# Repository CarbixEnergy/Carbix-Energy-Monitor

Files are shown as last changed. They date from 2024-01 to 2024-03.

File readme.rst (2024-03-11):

=========================================
Carbix Energy Monitor Project
=========================================

This is an open-source, open hardware project for monitoring energy,
forked from `IotaWatt <https://github.com/boblemaire/IoTaWatt>`_.
**We are committed to continuously optimizing supply chain costs to provide affordable hardware devices
and promote updates for this project.**

It can use any of dozens of common current transformers and will report the data locally via an integrated web server,
or upload to any of several third-party energy websites/databases.
Configuration and administration are through an easy-to-use browser-based utility running on a computer,
tablet, or smartphone.

CarbixEnergyMonitor is a full-function standalone energy monitor with the capability to store and
serve up to 15 years (or more) of comprehensive usage data and has an integrated web server with visualization apps.
At the same time, it can upload data to any of several (and counting) web-based databases and reporting systems.

Hardware is open and uses an ESP8266 nodeMCU, MCP3208 12-bit ADCs, an RTC, and an 8G SD card.

Metrics accumulated to 5-second resolution are Voltage(V), Power(Watts), Energy(kWh), VA, and PF.
While not certified to a standard, users typically report accuracy within 1% of their revenue meters.

Taking advantage of China's cost-effective supply chain, we will provide more reliable,
lower-priced energy monitors to quickly promote project development.
Now We sell Carbix energy monitor kit and current sensor accessories on `Amazon US <https://www.amazon.com/Monitor-CIRCUIT-Electricity-Open-Source-Open-Hardware/dp/B0CTCNH859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>`_,
allowing users to purchase according to their needs. For this equipment,
there is still a lot of room for cost optimization, which requires us to have a certain scale effect,
and we will work hard for this.

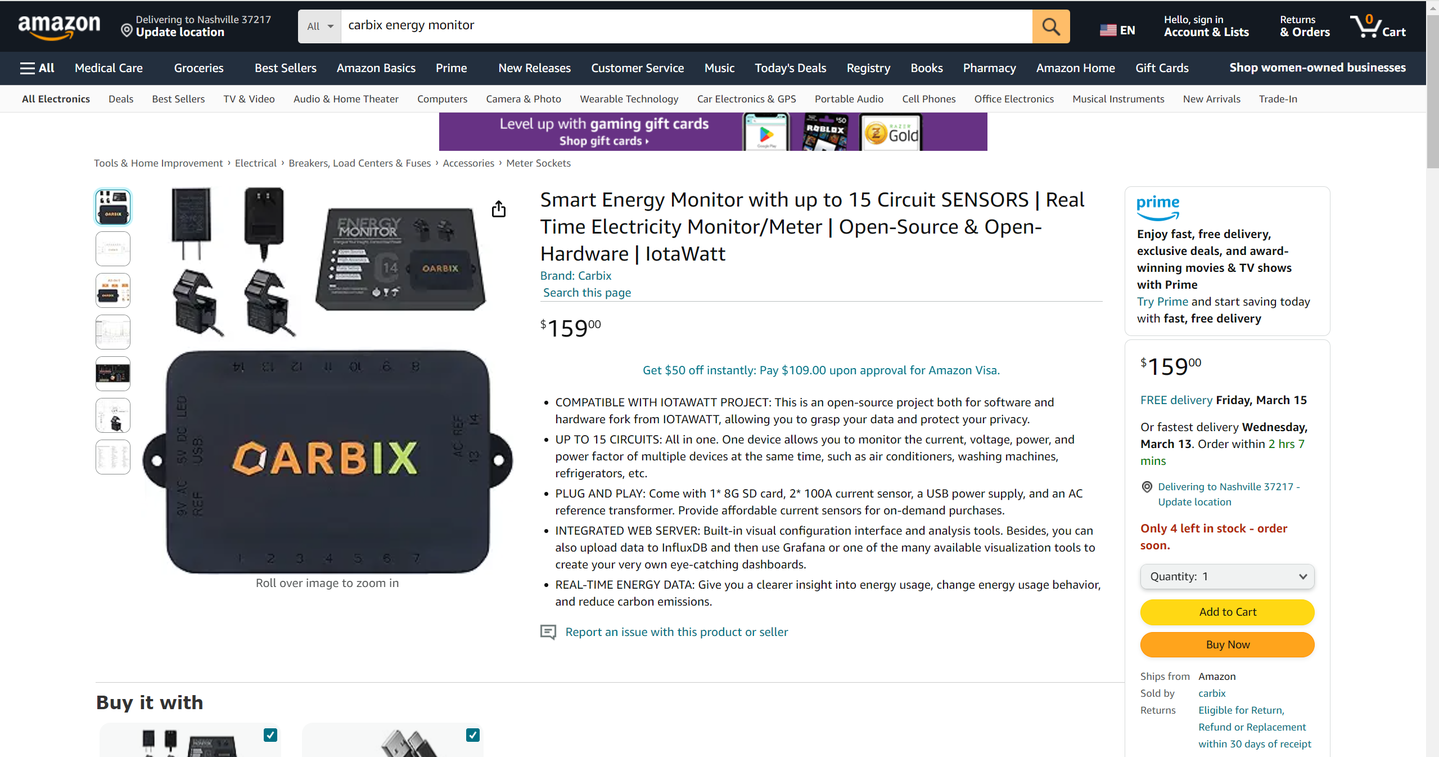
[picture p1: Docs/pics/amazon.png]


Thanks to Bob Lemaire the founder of IotaWatt for doing such a great job, we will continue to promote the open source development of this project.

`Documentation <https://carbix-energy-monitor.readthedocs.io/en/latest/>`_

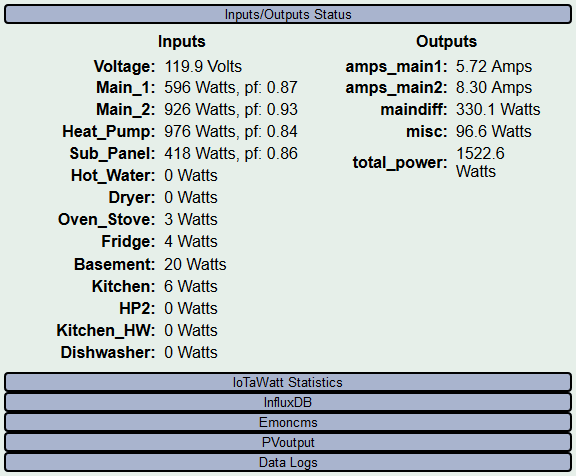
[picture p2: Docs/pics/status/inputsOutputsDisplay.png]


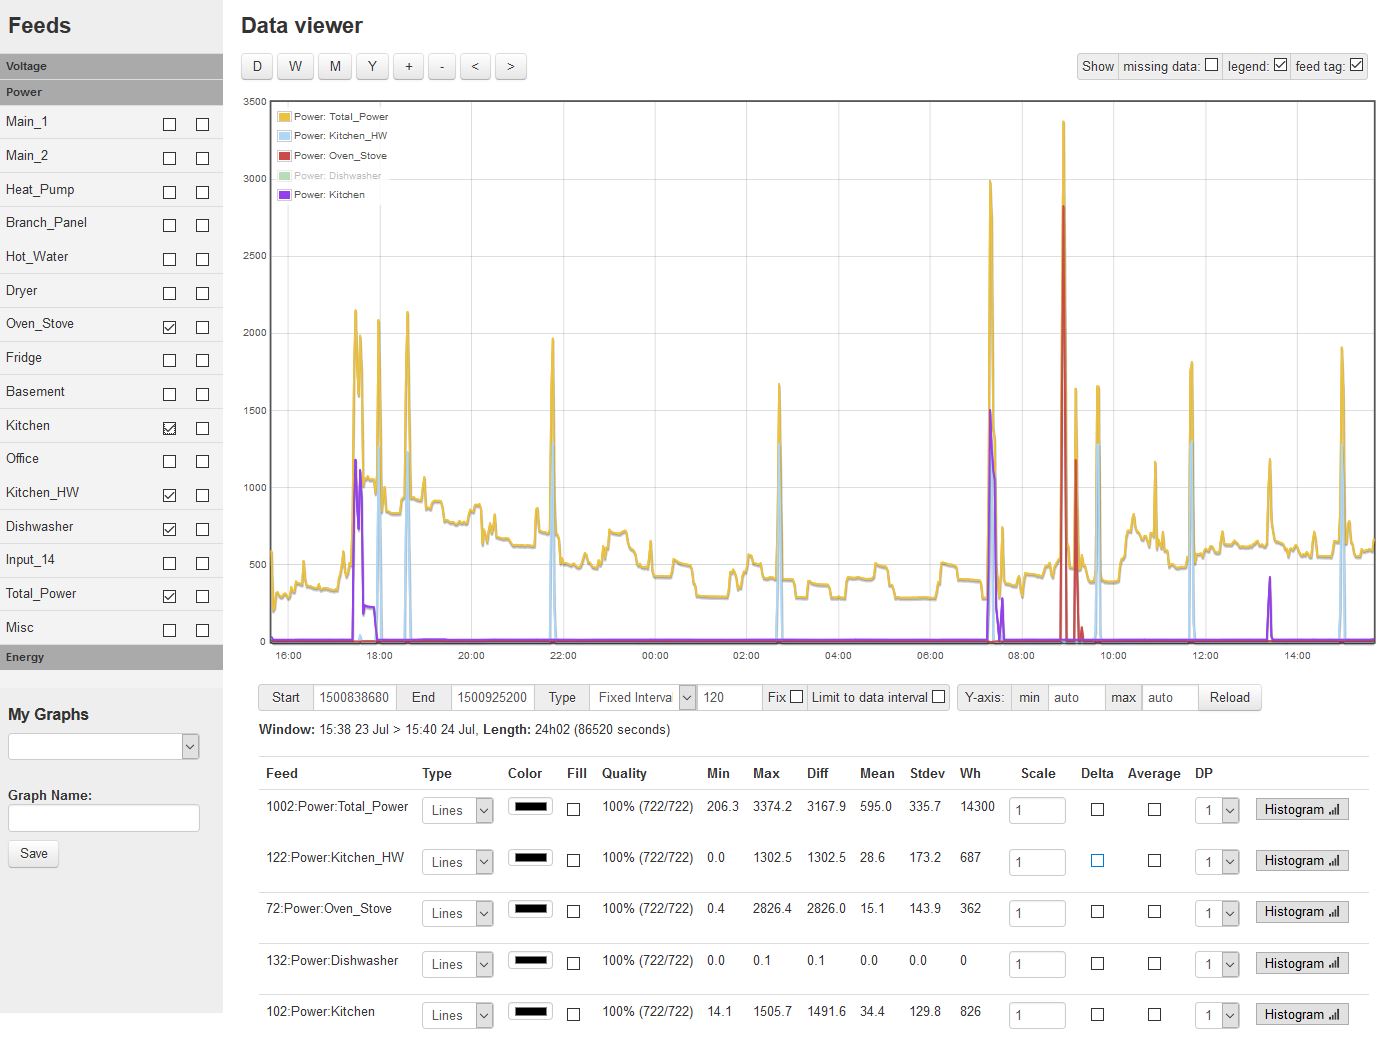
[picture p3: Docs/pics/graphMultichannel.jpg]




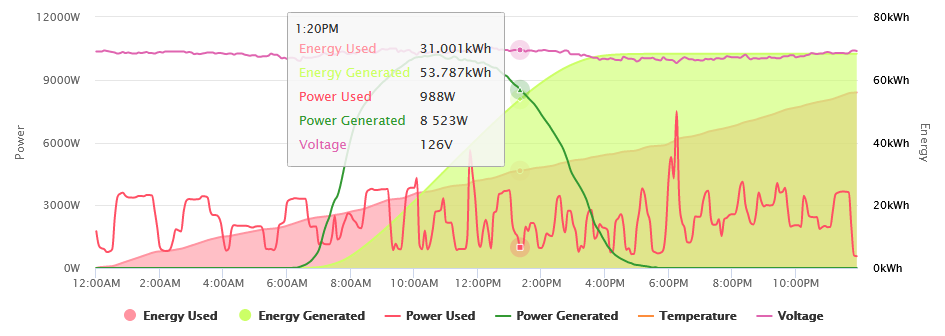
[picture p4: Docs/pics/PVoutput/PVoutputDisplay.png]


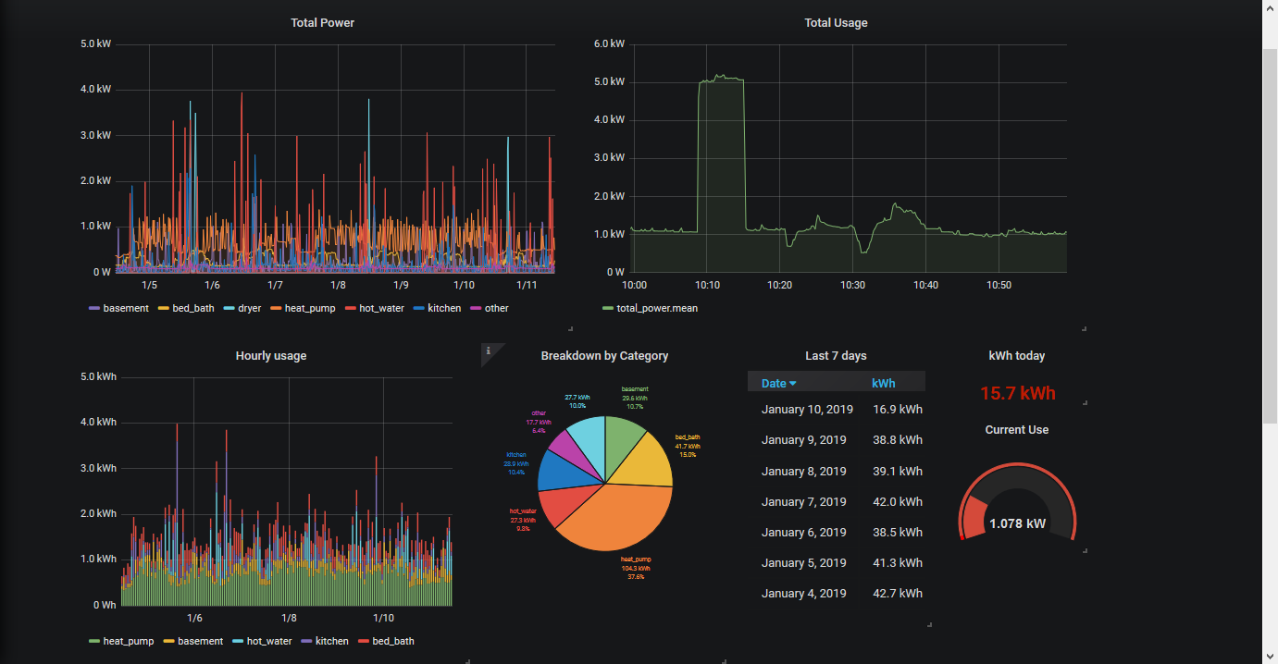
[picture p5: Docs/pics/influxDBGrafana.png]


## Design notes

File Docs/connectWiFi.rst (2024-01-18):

==================
Connecting to WiFi
==================

Purpose
-------

When CarbixEnergyMonitor powers up, it attempts to connect to the
last WiFi network used.
A connection must be established to an internet connected network if the real
time clock is not set, or to run the configuration utility,
or if logging to an external server like Emoncms is desired.
*It is strongly recommended to connect the CarbixEnergyMonitor to a WiFi network
with a reliable internet connection*.

If the power-up connection is successful, 
the LED will begin to glow dull green.
This indicates that the CarbixEnergyMonitor has connected
and is in normal operating mode.
At this point you can skip ahead to the next 
section `Device Configuration <devConfig.html>`__

New connection
--------------

If the CarbixEnergyMonitor has never been connected to a WiFi network (new),
or the last used network is not available, the ESP8266 will enter
AP (Access Point) mode when powered-up (not on a software restart).
This state is indicated when the LED flashes the 
three color sequence RED-GREEN-GREEN.
It will broadcast an SSID recognizable by the 
prefix ``carbix`` followed by a unique number.
Connect to it using a smartphone or tablet.  
Use the password ``CarbixEnergyMonitor`` (case sensitive).
If the device was previously configured and the 
device name was changed,
that new name will be the password required in this step.

After connecting, a page will be rendered with several choices.  Select ``Configure WiFi``.

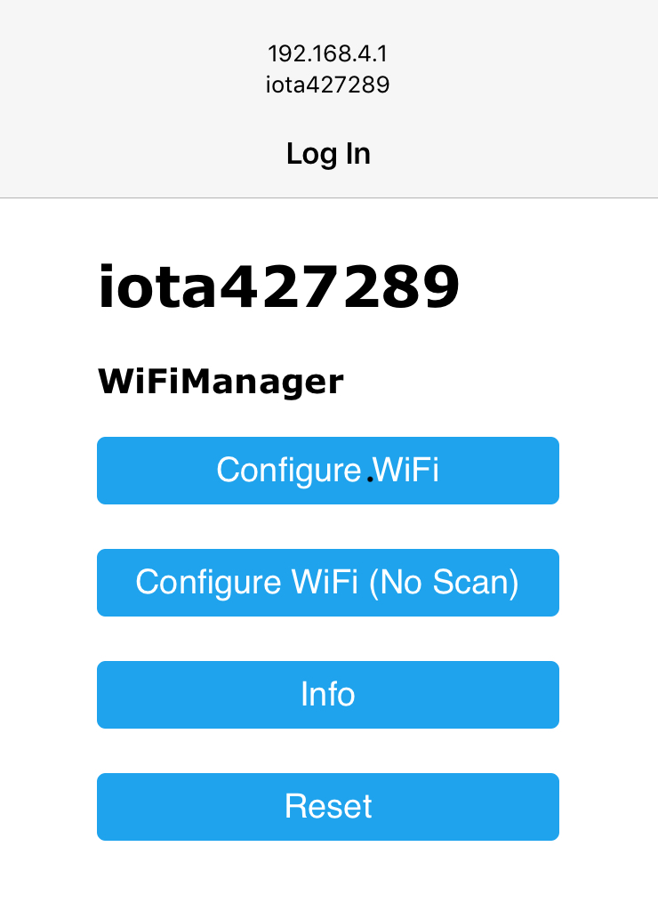
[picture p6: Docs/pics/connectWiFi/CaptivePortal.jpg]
captive portal image


A few seconds may elapse while the CarbixEnergyMonitor scans for the local networks,
then another page will be rendered allowing you to select one of the listed
networks, or specify another network not listed.

Note that the CarbixEnergyMonitor only supports 2.4 GHz wireless networks. If you have a 5 GHz
only network you can either enable 2.4 GHz on it, or create a separate (optionally hidden)
network on 2.4 GHz for the CarbixEnergyMonitor to use.

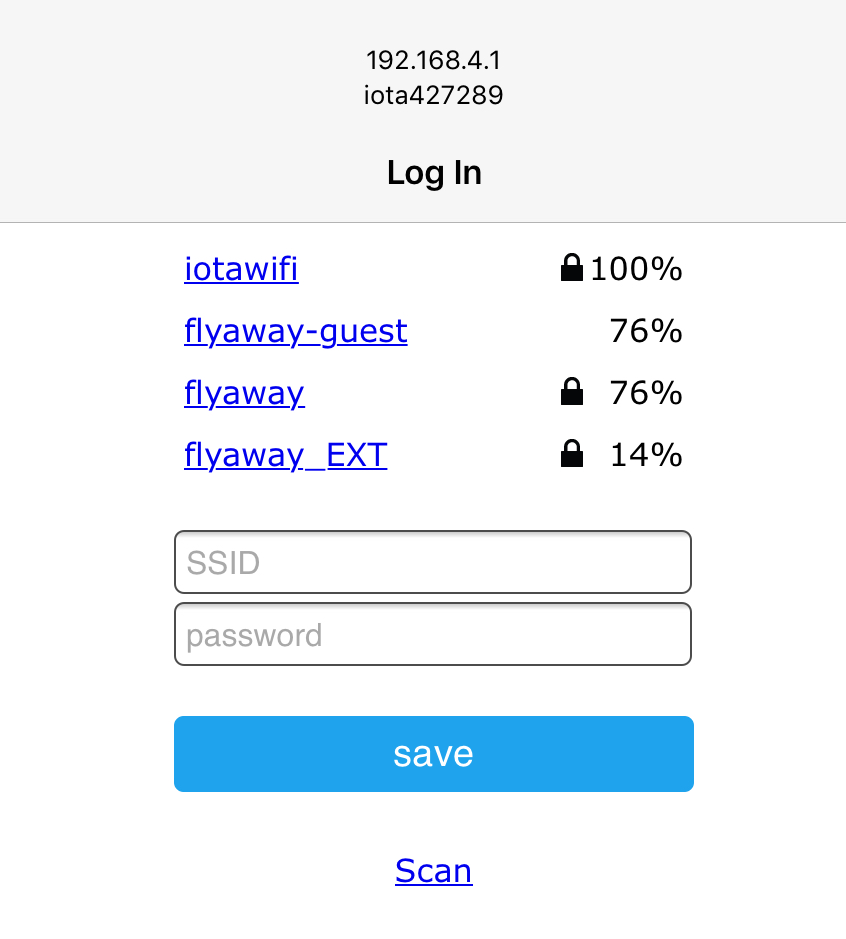
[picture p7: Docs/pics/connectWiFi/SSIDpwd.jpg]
Specify Network image


Select your network and enter the password, then save. Once connected,
the new WiFi network credentials will be saved and the device 
will continue it's
startup procedure.  If you see another LED sequence, refer to 
the `troubleshooting <troubleshooting.html>`__ section.

When the LED glows dull green, proceed to the next step
`Device Configuration  <devConfig.html>`__

Resetting WiFi to Defaults
--------------------------

If you wish to change the WiFi SSID that the CarbixEnergyMonitor is connected to
(you might have done some testing and want to deploy 'live' somewhere where the SSID is different)
BEFORE moving the device you should reset the WiFi.

Using the configuration app go to ``Tools->WiFi``

Disconnect WiFi image

After the command to disconnect the existing WiFi connection has been sent, 
CarbixEnergyMonitor will respond "ok" and the LED will change from a dull green to a dull red as the CarbixEnergyMonitor disconnects,
indicating that the WiFi link has been severed.

Then power cycle the CarbixEnergyMonitor. It should restart with the RED-GREEN-GREEN led sequence like a new
CarbixEnergyMonitor ready to connect to the new SSID

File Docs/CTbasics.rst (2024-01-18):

=========
CT Basics
=========

What is a Current Transformer?
------------------------------

`From Wikipedia <https://en.wikipedia.org/wiki/Current_transformer>`_:

    *A current transformer (CT) is a type of transformer that 
    is used to measure alternating current (AC). 
    It produces a current in its secondary which is 
    proportional to the current in its primary.* 

In our case, the primary is *one* of the conductors of the circuit
that we want to measure, and the secondary is the output jack
that plugs into the CarbixEnergyMonitor.

So without connecting anything directly to any high-voltage
wiring, it's possible to get a scaled down measure of the
primary current that can be used to passively measure power 
(Watts) of a circuit.

Types of CTs
------------

CTs come in various types, sizes, and capacities, 
and are made for a variety of end uses. This tutorial
doesn't try to address all aspects.  That's what
Wikipedia does well.  Here we'll try to focus on the
CTs that are suited to use with the CarbixEnergyMonitor in typical
scenarios.

Physically, a CT needs to have an iron core through
which one or more primary conductors pass. The most basic
type is a solid-core CT, where an iron doughnut is wrapped 
with turns of wire. This type of CT is relatively inexpensive,
typically very accurate, but requires that the primary
conductor be disconnected and reconnected to install, thus
exposing the installer to high-voltage and disrupting the
primary circuit.

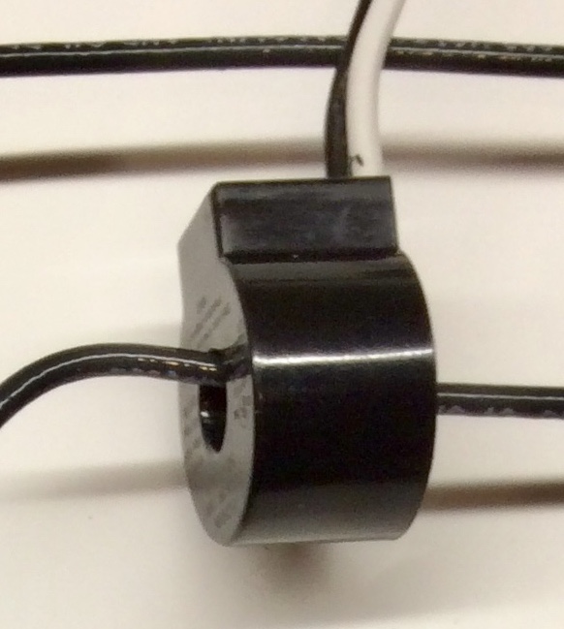
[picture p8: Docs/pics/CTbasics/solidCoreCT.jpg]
Solid Core CT


    Solid Core CT

Split-core CTs also require an iron core around the primary,
but do so using two hinged halves that mate to form the continuous
iron loop. This type of CT can be installed by simply snapping
the two halves over an active primary conductor.

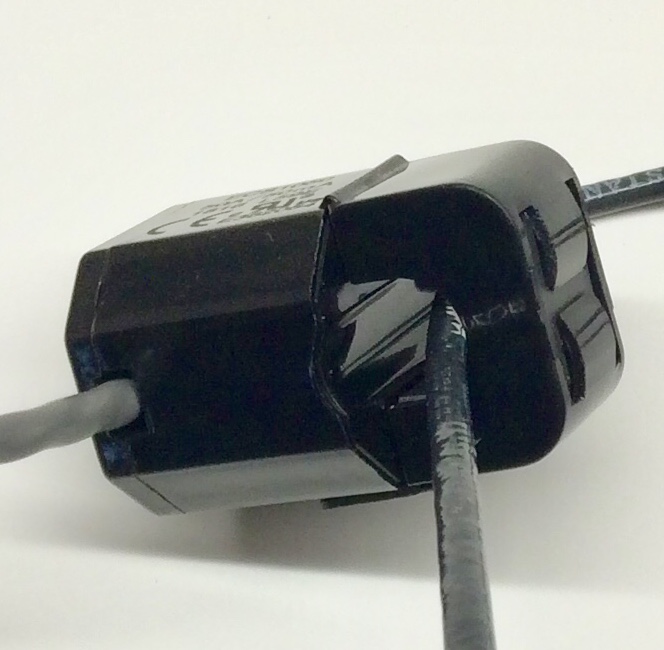
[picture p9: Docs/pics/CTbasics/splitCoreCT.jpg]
Split Core CT


    Split Core CT

Installation
------------

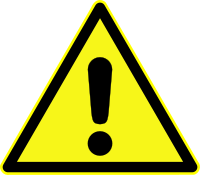
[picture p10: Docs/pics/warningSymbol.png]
**Warning!**


*The installation of CTs can be dangerous and/or
cause hazardous situations resulting serious injury or death.
Worldwide, there are a variety of electrical conventions, regulations 
and standards.  It is the user's responsibility to insure that the 
installer is qualified and all local codes and regulations are followed.*

To measure the current in a circuit, a CT is installed on one, and 
only one, of the conductors in a circuit. Either the conductor is
passed through the solid-core, or the split-core is clamped over it.

CTs must have a load.  Without a load, they will develop very 
high voltages that can damage the core windings and/or 
create a safety hazard. When plugged into the CarbixEnergyMonitor, the
secondary windings are loaded by a *burden resistor*.

Some CTs have protective diodes, called TVS diodes, that will 
protect against damage when unplugged for short periods.  Even if
a diode protected CT is to be unplugged for an extended length 
of time where the primary is energized, the CT should be removed 
or shorted.  Shorting will not damage the CT.

Polarity
--------

CTs are manufactured to produce a secondary current that is in 
phase with the primary current when installed with a particular 
orientation. In single and split-phase installations it is
important to observe polarity in certain situations.  In
three-phase installations, it is imperitive that a polarity 
convention be observed.

CarbixEnergyMonitor will accept many different CTs from different manufacturers.
While most have some type of markings that can be used as a 
reference for polarity, there is no universal standard.  Typically,
CTs from the same manufacturer will be consistent with respect to source 
and load indicators.

And so it is for the Echun and AccuEnergy CTs that CarbixEnergyMonitor, Inc makes available.
When installing, we use the notion of a *source* and a *load*.
The source can be conceptualized as *where the power comes from* 
and the load as *where the power goes*.

So for the mains, or incoming power to a service, the *source* would 
be the meter side, or incoming power feed.  The *load* would be the 
main circuit breaker or fuse side.

For branch circuits, it would be just the opposite.  The *source* would
be the circuit-breaker side, and the *load* would be the appliance side.

For a solar inverter connection, the *source* would be the inverter side, 
and the *load* would be the circuit-breaker or other point of
interconnect.

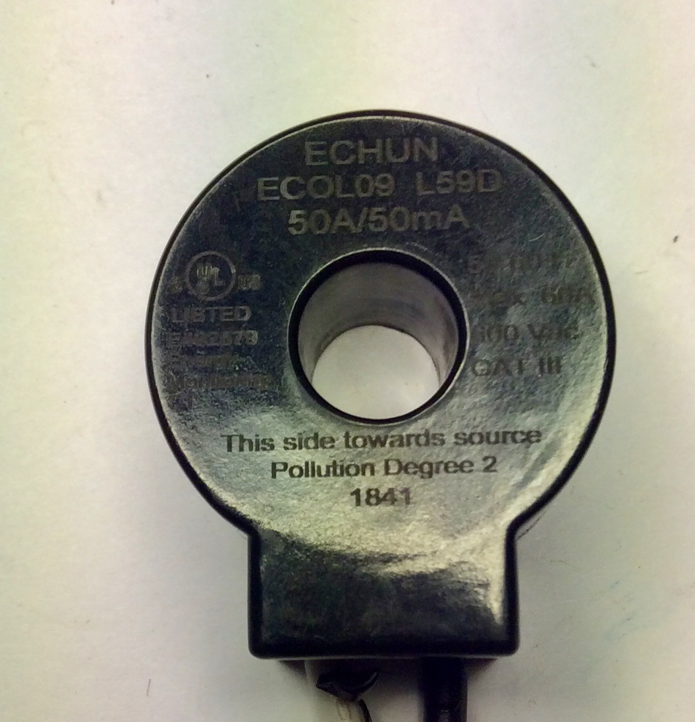
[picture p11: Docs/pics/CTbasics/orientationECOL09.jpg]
ECOL09


    Here you can plainly see "This side toward source"

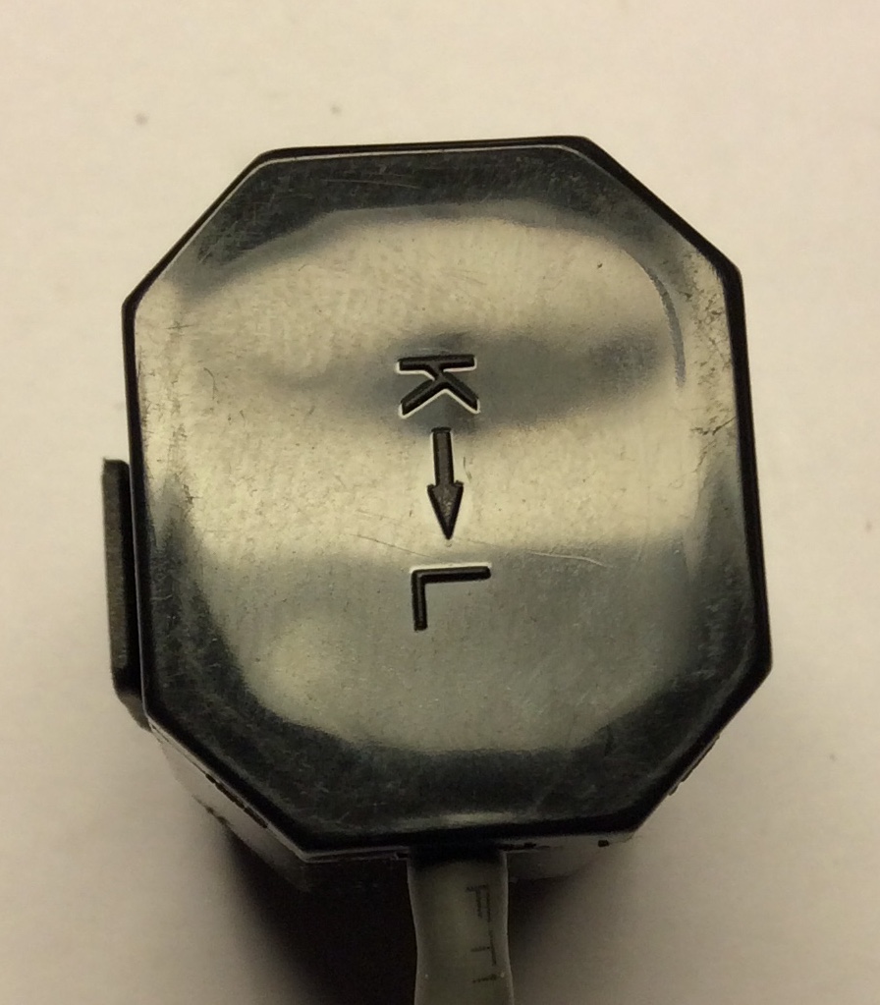
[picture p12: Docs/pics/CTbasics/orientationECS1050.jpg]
ECS1050


    Here the arrow points source(K)->load(L)

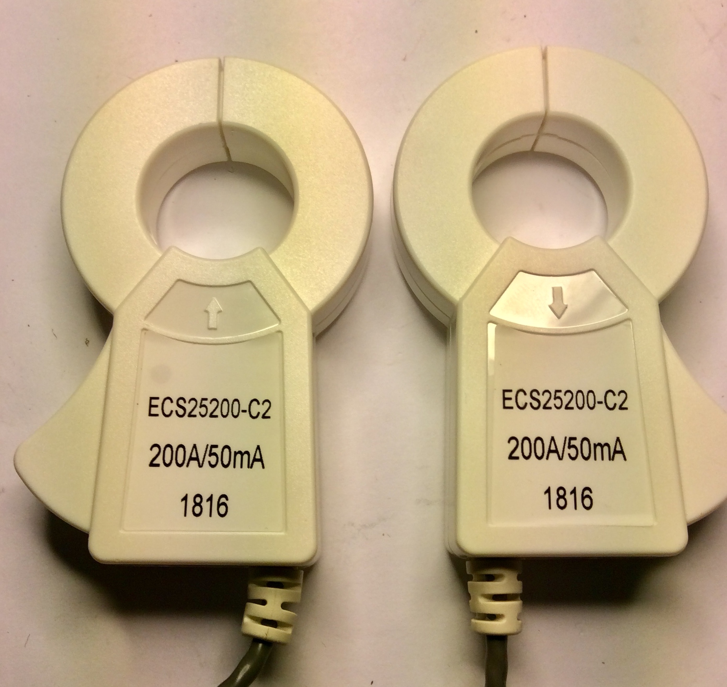
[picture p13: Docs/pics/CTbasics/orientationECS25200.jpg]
ECS25200


    This is an Echun ECS25200 clamp type CT
    used for 200A mains. Both sides are shown.
    Note the arrows just under the opening.
    The arrow pointing up to the opening
    indicates the source side, and the down
    arrow indicates the load side.

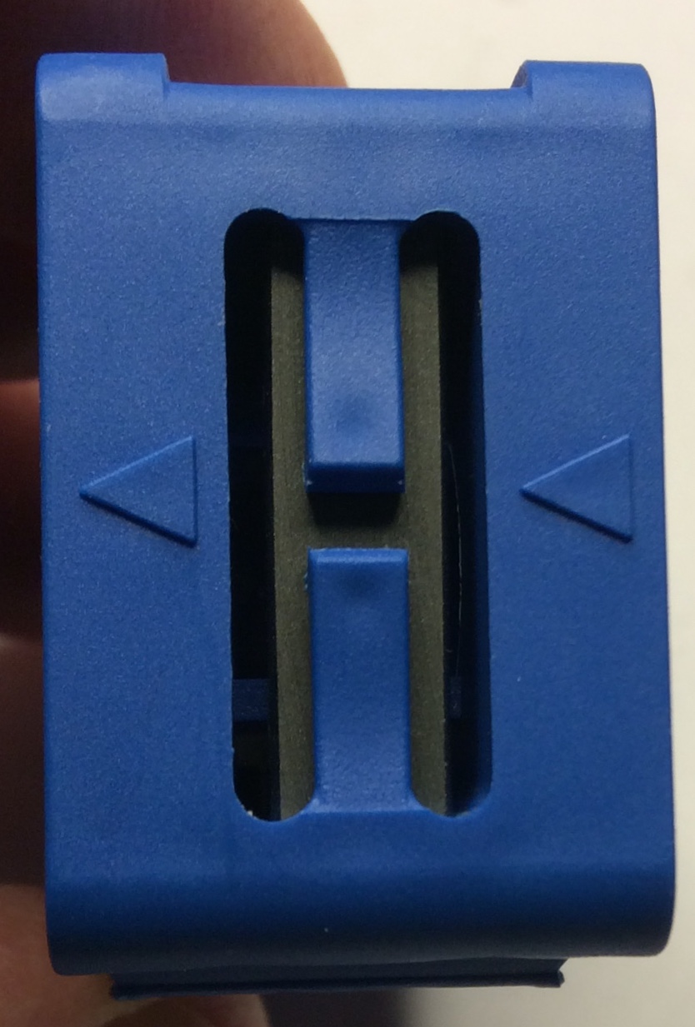
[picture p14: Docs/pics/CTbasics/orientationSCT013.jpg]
SCT013


    This is the common SCT013 CT.  If you are using
    them exclusively, the arrow can be aligned consistently
    as source to load.  But note that if using with 
    the Echun CTs, they must be installed with the
    arrow pointing from load to source.  This isn't
    a fault of either manufacturer.  It just reflects
    the lack of a standard for how to connect the
    CT secondary to the 3.5mm jack used to connect.

Single and three-phase systems
------------------------------

All of the CTs in single or three-phase systems should
be installed identically with respect to load and 
source.  This is especially important when configuring 
three-phase systems using the 
`Derived Three-phase <threePhase.html>`_ method.

Split-phase systems
-------------------

Most of North America and some Asian countries use 
a split-phase power system with dual voltage, typically 
120/240V.  With this power system, there are two mains 
with exact opposite phase. The voltage between either
main and neutral is 120V, while the voltage between 
the two mains is 240V.  This provides an advantage of 
the relative safety of lower voltage in small appliance
outlets, while still providing high voltage for 
workhorse appliances like water-heaters, ranges, 
and clothes dryers.

In these systems, while possible to use two voltage references,
typical CarbixEnergyMonitor installations use a single reference
that reflects the phase and voltage of one of the sides, 
or *legs* as they are commonly called. The result is that 
CTs on the other leg should be oriented  the opposite way to
be in phase with the opposite voltage reference. For simple singlephase 120V
(or 230V European type) circuits, CarbixEnergyMonitor will automatically correct
reversed CTs and report positive power unless "Allow negative values" is
enabled in setup for that CT.

There is more to installing CTs on 240V circuits in split-phase 
systems in the next chapter.

240V Split-phase circuits
-------------------------

As explained above, split-phase systems can provide 
high-voltage for large appliances. These circuits are connected 
to two adjascent CTs that are on different legs.  The usual
convention is to use RED and BLACK wires or, as explained below, 
BLACK and WHITE for *pure* 240V circuits.

240V only
^^^^^^^^^

When I say *pure* 240V circuits, I mean circuits that are 
usually a single load, and do not have a third neutral wire 
to use either leg independently for 120V.  Examples of *pure* 240V 
circuits would be a resistive water-heater, well-pump and 
baseboard electric heater. What these circuits will have in common
is that they don't have a neutral wire, and usually use two 
conductor with ground BLACK and WHITE leads.

With these circuits, you can place the CT on just one of the
conductors, and check the *double* box in input configuration, 
directing CarbixEnergyMonitor to double the voltage value to report
correct power and amperage.

120/240V circuits
^^^^^^^^^^^^^^^^^

Like the *pure* 240V circuits above, these circuits use two 
adjascent circuit-breakers, but also have a neutral conductor. 
They usually have RED and BLACK conductors on the circuit-breaker 
and a white neutral conductor that connects to the neutral bussbar. 
Typical appliances are ranges, ovens, and clothes-dryers.  Circuits
feeding sub-panels are usually of this type as well.

For these circuits, the two legs must be measured individually 
because the current in each is not always the same.  There are a couple 
of ways to do this.

The easiest way is to pass both the RED and BLACK conductors through 
the CT.  A CT will measure the total current of all of the conductors 
that pass through the primary.  But there is a twist.  The phase of 
the current in each conductor is exactly opposite the other, so they 
will cancel each other out. Rather than get the sum of the two,
you get the difference between the two.

The solution is to pass one conductor through in the opposite direction 
to the other.  There is a common trick for this.  In many panels,
the conductors are brought past the CT in a U shape so that there is
some excess wire in case the circuit needs to be moved within the panel. 
You can use this U configuration to easily reverse one of the conductors.
In this case, the CT needs to handle the combined capacity of the two 
circuit breakers when added together.  
A 50A CT can probably be used up to about a 2x30A breaker.

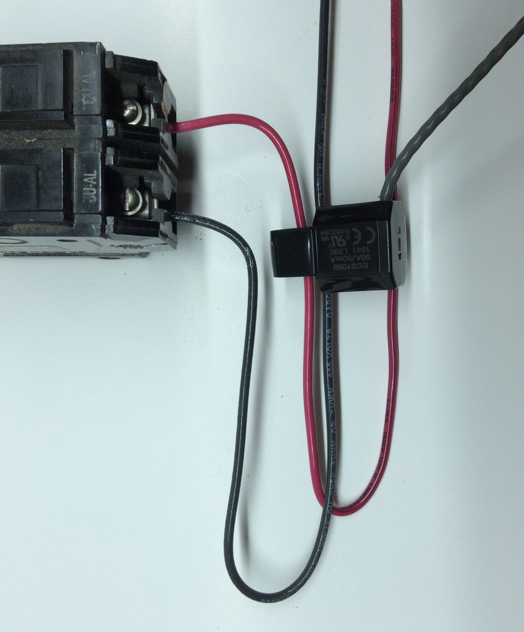
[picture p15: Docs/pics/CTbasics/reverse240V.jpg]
Reversed CT conductors


    The CT is clamped around the RED wire going down and 
    the BLACK wire going up.

An alternate method, and recommended with high amperage 
sub-panel circuits, is to put a separate CT on each leg. 
The CTs can be connected to two individual CarbixEnergyMonitor inputs
and added together later for the total.  With this method, 
each of the two CTs only need match the capacity of one of 
the circuit breakers.

Two individual CTs can also be combined with a common headphone
splitter and fed into a single CarbixEnergyMonitor input. When combining
this way, both CTs must be the same model with an individual 
capacity sufficient to measure the combined capacity of the two 
circuit breakers.

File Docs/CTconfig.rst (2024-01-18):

================================
Configuring Power Channels (CTs)
================================

What is a power channel?
------------------------

Power channels measure the current flow through a circuit and 
combine that with the reference voltage to determine power, 
expressed in watts, and to accumulate energy used, expressed in watt-hours.  
Current through a circuit is measured indirectly by installing a passive 
sensor, called a *current transformer* (CT), around one of the conductors 
in the circuit. 
CTs come in a various capacities, physical connection type, and electrical output.  

The good news is that CarbixEnergyMonitor supports a wide variety of readily available
CTs, and many can be configured simply by selecting the model from a list. 
CTs are connected with 3.5mm stereo jacks (headphone jacks). 

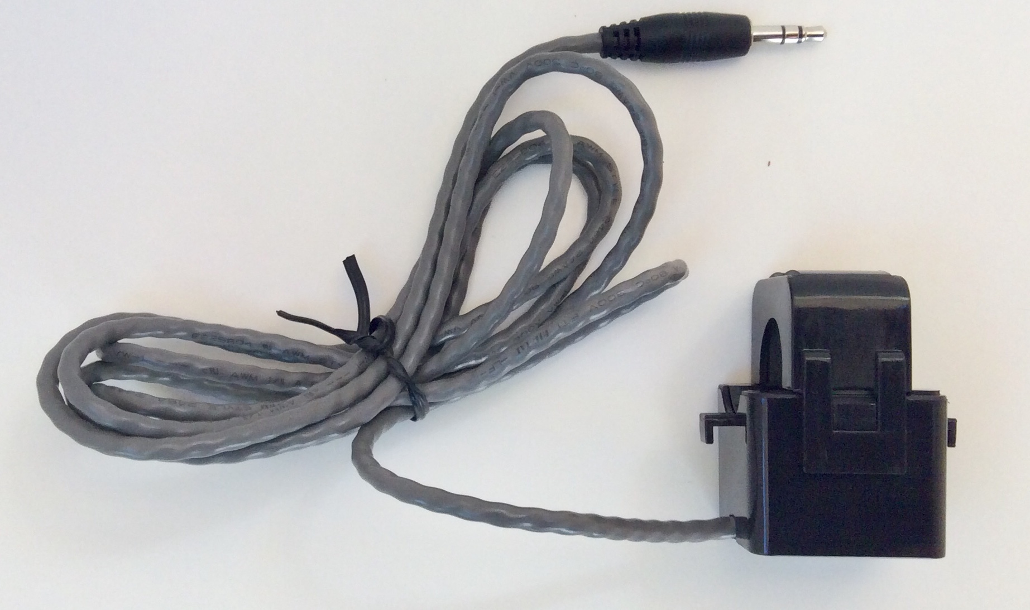
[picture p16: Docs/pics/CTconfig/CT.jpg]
Echun ECS16-100


    Echun ECS16-100 CT

Connecting the CTs
------------------

This tutorial does not cover physical installation of the CTs to your 
electrical circuits. That should be done by someone familiar with 
electrical wiring. Your qualified installer will know how to do this. 
The 3.5mm connectors plug into any of the 14 input channels on the CarbixEnergyMonitor.

The only additional recommendation is that all of the CTs be oriented 
the same way with respect to current flow.  
Most CTs have an arrow or other marking to aid in consistent orientation. 
Not to worry, in the event some end up backward, CarbixEnergyMonitor will still work,
will tell you which ones appear to be backward, and provides a way to correct virtually.

You can find more detailed information about physical installation of CTs 
in the `CT Basics <CTbasics.html>`_ section.

Configuring the Input Channels
------------------------------

At this point, you should have the CarbixEnergyMonitor up and running with the voltage
channel connected, configured, and calibrated if necessary. 
You are using the config app in a browser connected to your WiFi network.  
Hover over **Setup button** and click |inputs| in the dropdown buttons.

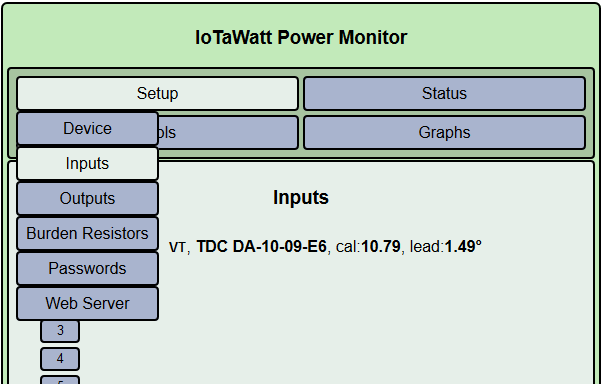
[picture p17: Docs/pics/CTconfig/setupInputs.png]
Setup Inputs List


This screen should look familiar. We came here to configure the voltage 
transformer (VT). Now we will configure current transformers (CTs) to other 
inputs. To add or edit the CT specification for an input channel, 
click the channel's number button. Let's add a CT to channel **Input 1 button**.

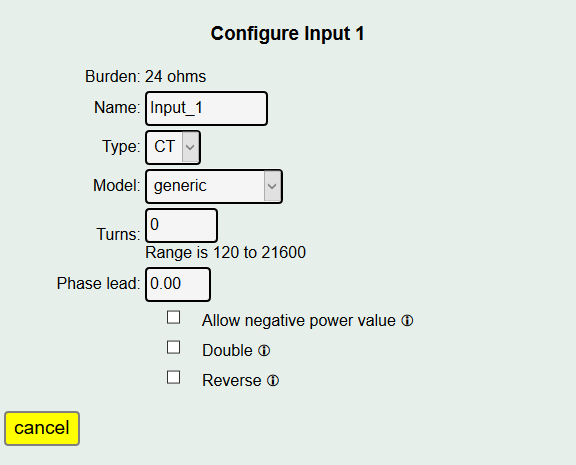
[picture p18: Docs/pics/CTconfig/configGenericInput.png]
Config Generic CT


The app enters channel edit mode. Here you specify the model and other 
details about the CT connected to this particular channel.  
But first, it is helpful to name the channel by typing a name in the 
name box. You can just use the default "Input_1" or something more 
meaningful like "Kitchen" or "Living Room" or "Main". 
We will configure one of our US 120/240V split-phase mains
as **main_1**.

The default type is **CT** and that's correct.

The next drop-down box is the model of the CT.  
Initially it will be `generic`, 
Click the drop-down list and select the **ECS24200** CT.  

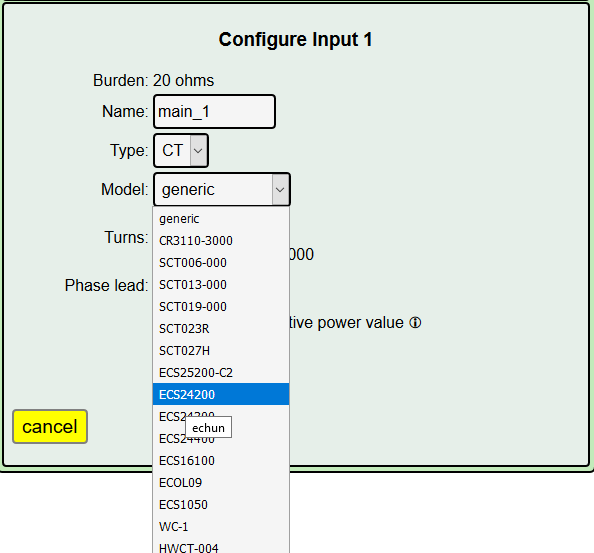
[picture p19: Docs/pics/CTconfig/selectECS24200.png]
Select ECS24200 CT


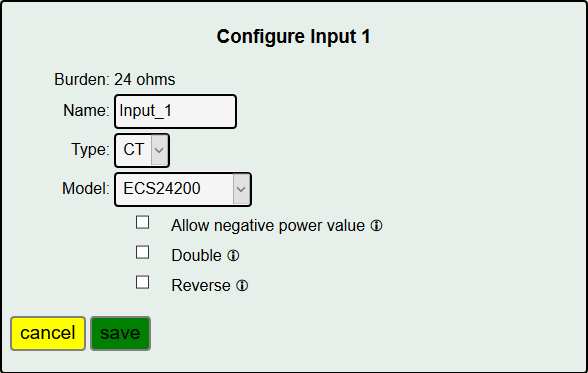
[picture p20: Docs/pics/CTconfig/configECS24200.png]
Config ECS24200 CT


Notice that after selecting a specific device from the table, 
the input fields for "turns" and "phase" disappear.  
That's because those values are known for the listed CTs.  
If you have a CT that is not found in the list, 
you will need specify the "generic" entry and 
provide the turns-ratio and phase-lead for that CT.
see `generic CT`_ below.

There are check-boxes to further configure the CT.  
Most of the time, these will not be used, but there are circumstances 
where you would check one or more of them. If you hover on the **!** 
next to each, a brief description will appear. They are explained below:

**Allow negative power value**
    This is typically checked only for mains in an installation with 
    grid-tied solar (net-metering).  Checking this box tells CarbixEnergyMonitor
    that it is normal for current to flow backward through this circuit, 
    as when a PV system creates more power than you are using locally 
    and the balance is "exported" to the grid.  When you check this 
    box you are affirming that the CT is installed correctly and that 
    negative power should not be automatically "corrected" to positive.

**Double**
    In North American split-phase power systems (120V/240V), 
    all circuits are assumed to be 120V.  When this option is selected, 
    power will be computed using double the value of the
    reference voltage, or nominally 240V. 
    Use this for 240V circuits where one CT has been applied to one 
    of the conductors and there is no neutral (white) wire used by the 
    appliance. Typical circuits would be Water Heater, Water Pump, 
    Mini-Split Heat-Pump. There are other ways to monitor 
    240V circuits as well.

**Reverse**
    Sometimes a CT is installed backwards with respect to normal 
    current flow.  
    CarbixEnergyMonitor will sense this and correct automatically in single-phase
    power systems. It will correct the negative value automatically and 
    indicate so in the status display with a little ↺ symbol. Selecting 
    this option will virtually reverse the CT as if it were oriented 
    correctly, obviating the need to physically reverse it.
    Doing so can be safer and/or easier, especially with solid core CTs. 
    While merely convenient for single-phase systems, correct orientation 
    is a necessity in three-phase installations because the CarbixEnergyMonitor
    cannot automatically sense a reversed CT and correct for it.

Press **Save** to finish.

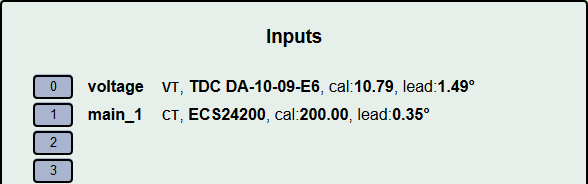
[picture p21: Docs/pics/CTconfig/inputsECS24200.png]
Inputs List w/ECS24200


That's it.  The screen returns to the complete list of inputs where you 
can add more channels or change the configuration of existing inputs. 
Each time you press save, the new configuration is sent to CarbixEnergyMonitor
and the changes take effect immediately. If the CTs are installed 
and connected, you will can see the power displayed in the 
Input Channel `Status screen <status.html>`_.

When you have configured all of the CTs connected to the CarbixEnergyMonitor,
basic configuration is complete.
Click the **Status button** button to see the CarbixEnergyMonitor in action.

The following additional information may provide guidance for more advanced installations.

Generic CT
----------

We just configured a *Current Type* CT that was of a model known to 
CarbixEnergyMonitor. If your particular CT is not one of the dropdown models,
you will need to describe the **generic** parameters. 
You will recall that this is the initial model designation for a 
CT when a new channel is added. Its also a drop-down choice when 
editing a CT channel. With this model selected, 
you must specify additional information depending on the type of CT:

Current Type CT
~~~~~~~~~~~~~~~

Current type CTs are the most common type of CT used with CarbixEnergyMonitor and
all of the CTs available in the Amazon Carbix Store are of this type.
They are typically described by the ratio of the maximum primary current 
that they can measure and the corresponding secondary current 
that will be produced, as in 200A:50mA. For these CTs, 
you will be asked to specify the "Turns:".  
This is the ratio of primary current/secondary current.  
So that 100A:50mA described above would be 100/.050 = 2000 turns.

Voltage Type CT
~~~~~~~~~~~~~~~

Voltage type CTs are typically described with an output in volts (V) and  
have an internal burden resistor that causes them to produce an output 
voltage rather than current.  They are connected to a modified CarbixEnergyMonitor
input that has had the internal burden resistor removed and specified as zero 
in the device configuration burden menu.  CarbixEnergyMonitor will ask for a **Cal**
factor. This is the primary current in amps that corresponds to 1 volt 
of output from the CT. An example of this is the SCT013-050 from YHDC.  
It is marked 50A/1V, so the **Cal** is 50.  Simple enough.

Phase
~~~~~

Both of the generic CT types above will also provide a place to specify 
**Phase**. Representative samples of the CTs in the model list have been 
tested to determine a phase correction value to compensate for phase 
shift of the transformer. If you have a generic CT a rule of thumb 
would be to use 2.0 for a split core CT (one that snaps onto a wire), 
and 0.2 for solid core CTs (Basically a solid doughnut that you pass 
the conductor through).

Enable derived three-phase
--------------------------

This checkbox enables advanced features used to configure inputs in a 
three-phase power system. Refer to the 
section `Three Phase Power <threePhase.html>`_ for more information.











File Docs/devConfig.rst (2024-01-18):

Device Configuration
====================

Successful startup will be indicated by a dull green glow on the LED.
If the LED is off, or blinking a sequence,
see the `troubleshooting <troubleshooting.html>`_ section.

After successful startup, you can connect to the device with your 
web browser to access the configuration app. 
Use the url: ``http://carbixenergymonitor.local`` or, if your device
has been renamed, use ``http://<newname>.local``. The configuration app starts with a row of buttons:

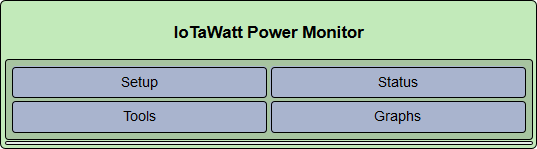
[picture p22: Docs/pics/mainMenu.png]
Main Menu image


Hover over **Setup button** and click **Device Button** in the dropdown menu.

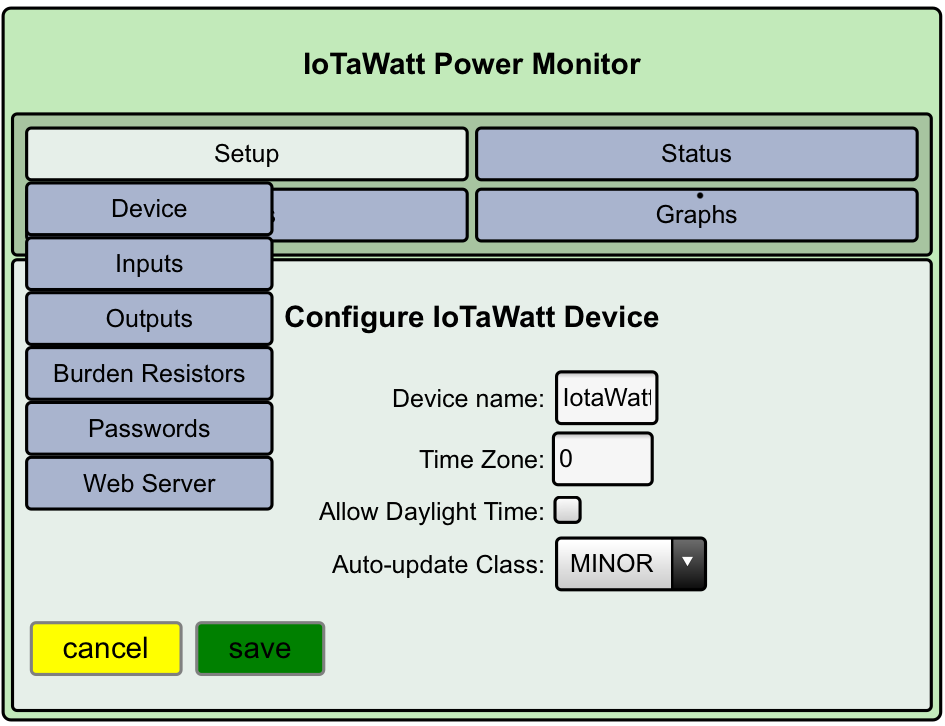
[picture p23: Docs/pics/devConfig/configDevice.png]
Config Device image


Device name
-----------

You can change the ``Device name`` to another 8 character name if you wish.
If you have more than one CarbixEnergyMonitor you will need to do this so that they
each have unique names. When you press save, the CarbixEnergyMonitor will restart using
the new name. From then on, ``http://<newname>.local`` will be the url
that you will use to access the device from your browser, and the new 
``Device name`` will be the password that you must use to 
connect to the AP if configuring for a different WiFi network.

TimeZone
--------

Set your local Time Zone relative to UTC time. 
All of the measurements are time stamped using UTC, 
but `log messages <messageLog.html>`_ and various reporting apps 
will use this offset to show the data in local time.

If your time zone is subject to "Daylight Saving Time", 
check the ``Allow Daylight Time`` box.
CarbixEnergyMonitor has DST rules for most of North America, Europe, Australia and New Zealand.

Auto-update Class
----------------- 

Auto-update Class tells CarbixEnergyMonitor if you want to receive
automatic updates of the firmware and what type of updates 
you are interested in. The choices are:

    :NONE:
        Do not Auto-update this device.
    :MAJOR:
        Only update major releases of the software.
    :MINOR:
        Update with minor releases. More frequent 
        but somewhat tested firmware. This is recommended.
    :BETA:
        Latest production firmware.
    :ALPHA:
        Recently released firmware with the latest features - 
        and the latest bugs.

CarbixEnergyMonitor checks the CarbixEnergyMonitor.com site for new software regularly.
The update process takes less than a minute.
New firmware is authenticated with a digital signature from CarbixEnergyMonitor and installed automatically.

Save
~~~~

Click **Save**. Your changes will be saved. 
If you changed the name of your device,
it will restart when you press save and you will need to 
restart the configuration application from ``http://<newname>.local``.

The next step is `VT Configuration <VTconfig.html>`__







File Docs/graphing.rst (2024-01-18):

========
Graphing
========

If you are uploading your data to Emoncms.org or influxDB, 
there are a variety of ways to organize and view your voltage,
power and energy use. The servers are fast and accessible 
from any place where there is internet connectivity. 
But there are some circumstances under which you may want to 
access your data locally:

*   You are not using Emoncms or influxDB to save your data.
*   You require finer resolution than is used in your Emoncms feeds.
*   You have output channels defined on your CarbixEnergyMonitor that are not
    replicated on Emoncms.
*   You want to post-process and view historic data using CarbixEnergyMonitor's
    output channel feature.

The local graphing feature is derived from the Emoncms graphing 
application and adapted to report the input and output channels 
of CarbixEnergyMonitor directly. It is available on devices
connected to the same WiFi network as the CarbixEnergyMonitor or on the
internet using local port forwarding.

From the configuration app click **Graphs Button**.

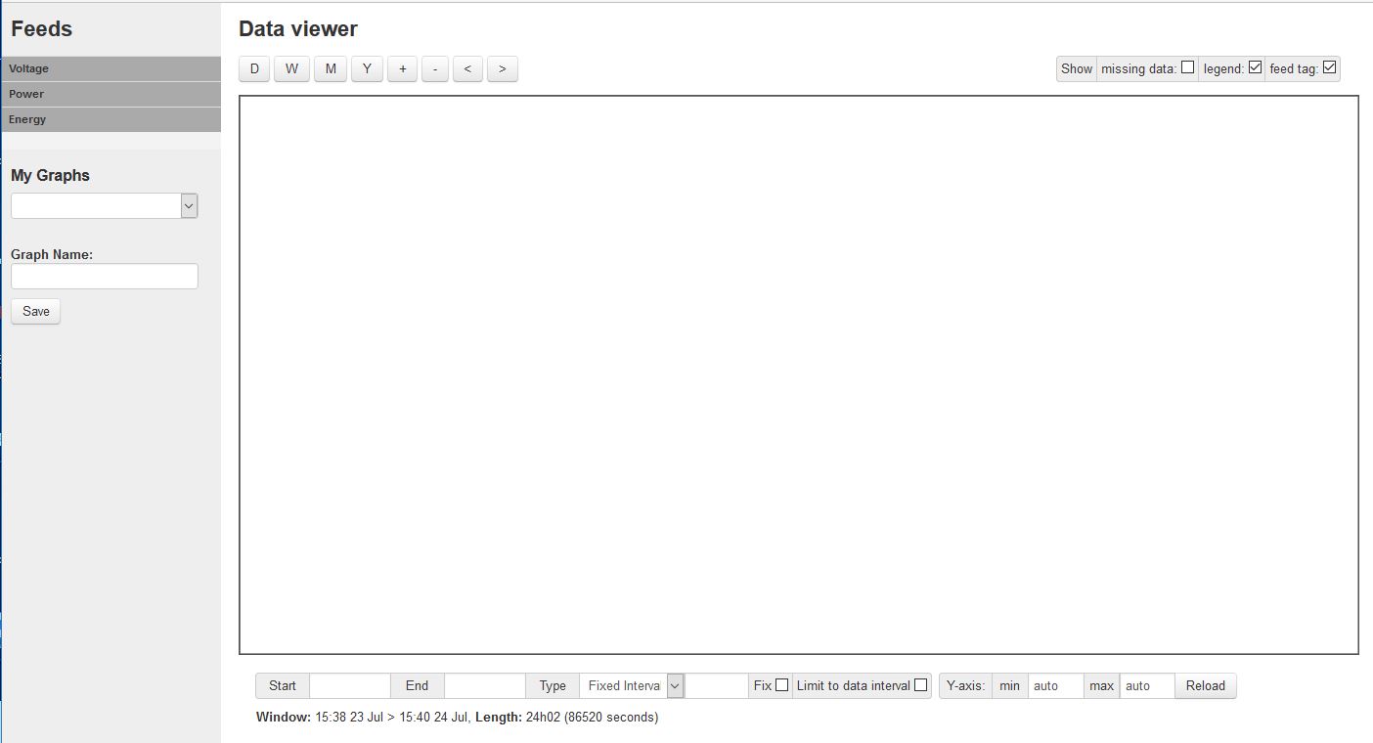
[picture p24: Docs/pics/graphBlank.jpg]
Blank Graph


Press the Voltage, Power, and Energy tabs under Feeds to list your 
CarbixEnergyMonitor input and output channels. Select the Power tab and then
select one or more of your channels listed there. Selecting 
Total_Power (actually an output channel that is the sum of Main_1 and Main_2) 
we get the following graph.

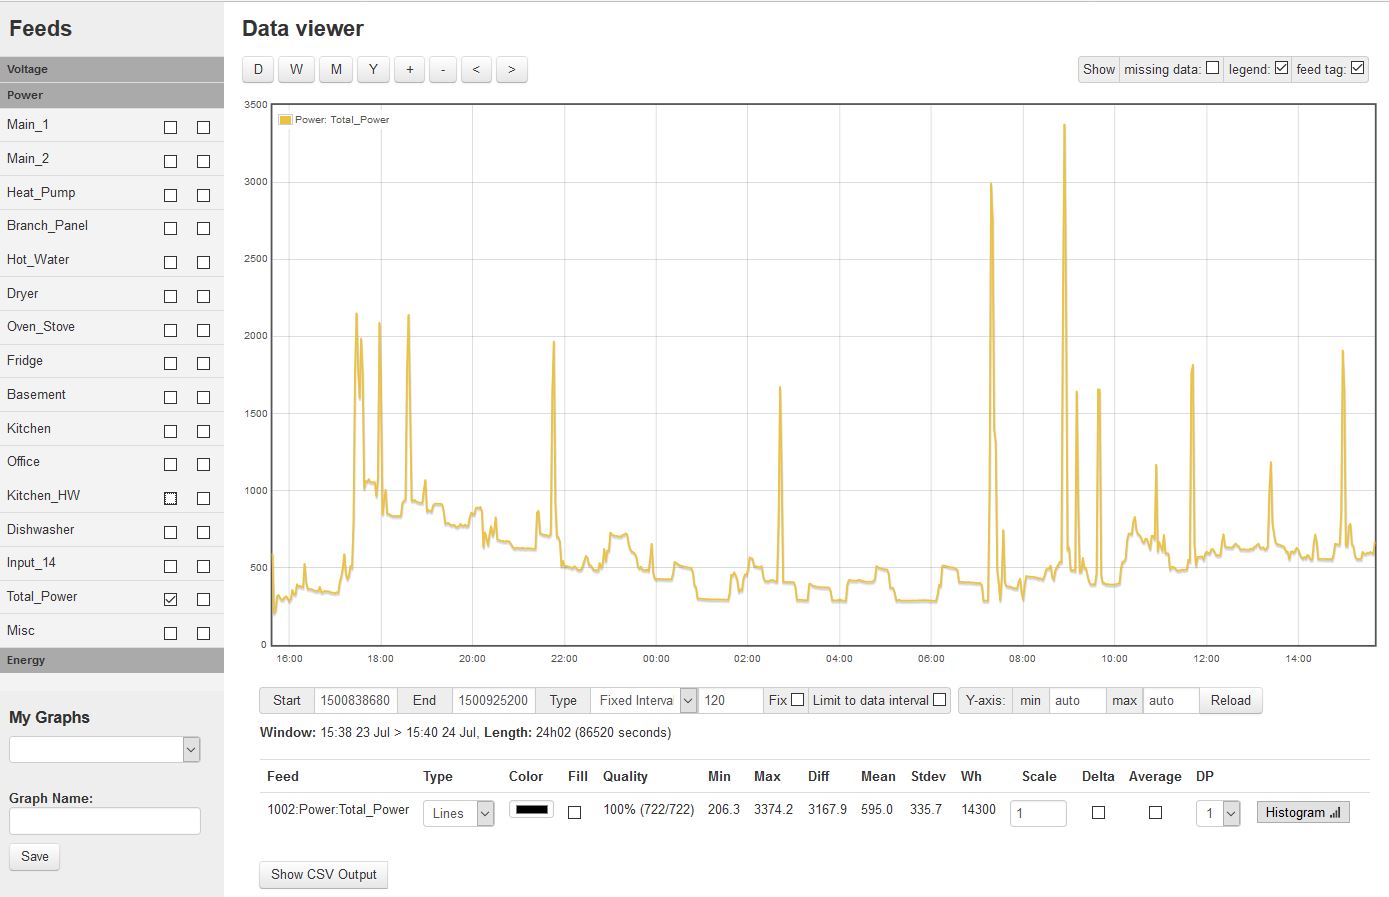
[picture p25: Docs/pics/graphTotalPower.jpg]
Total Power Graph


Notice that the graph covers a 24 hour period. 
That's the default. You can select the period using 
the D, W, M, Y buttons at the top, and you can move 
the time frame left or right and zoom in or out.

Back to this graph. It reveals that average power is about 600 watts. 
To be precise, the mean power is 595 watts and the total power 
for the day was 14,300 watt-hours (14.3Kwh) as indicated in the 
feed statistics at the bottom. Wondering what might be causing 
those spikes at various times throughout the day? 
Lets lay some other input channels on top.

Multi-channel Graph

Now the story unfolds. Most of the 1000 watt spikes are cycles 
of a point-of-use electric water heater in the Kitchen (Kitche_HW). 
The big spike around 9pm is the Oven/Stove circuit, and the rest 
of the spikes seem to line up with kitchen appliances.

That's just a sample of the power of the graphic presentation 
possible both locally and with essentially the same tool on Emoncms.org. 
Practically speaking, those power spikes are not the meat-and-potatoes 
of home energy use. Other circuits reveal the contribution of workhorse 
appliances like the refrigerator, freezer, 
heat-pump (not active this day), clothes dryer, 
computer and office machines. Kwh can be plotted as well, 
and compared to the whole. With 14 input channels, 
its possible to divide household usage into manageable components.



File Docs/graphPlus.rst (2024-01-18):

======
Graph+
======

Available with release 02_05_00.

This data visualization application runs in any browser to graphically present 
any of the data stored in the CarbixEnergyMonitor. It features relative and absolute time period selection
and handles all units of measure supported by CarbixEnergyMonitor. You can produce line and/or bar charts
with optional stacking and fill. Real-time graphs can be set to automatically refresh.  
Once created, any graph specification can be saved for quick future use.

The application is fully adaptive so it will work well on a full range of 
devices from mobile to desktop.  

The window can be broken down into four parts, each serving a different function:

* `Unit/Source selector`_
* `Time period selector`_
* `Graph window`_
* `Trace tables and options`_

Below is a complete window with all of the parts. 
We're plotting power for the current day
(midnight to 5:42pm).  Along with that we've plotted the accrued Watt-hours for the day, 
14.2 kWh as of 5:42.

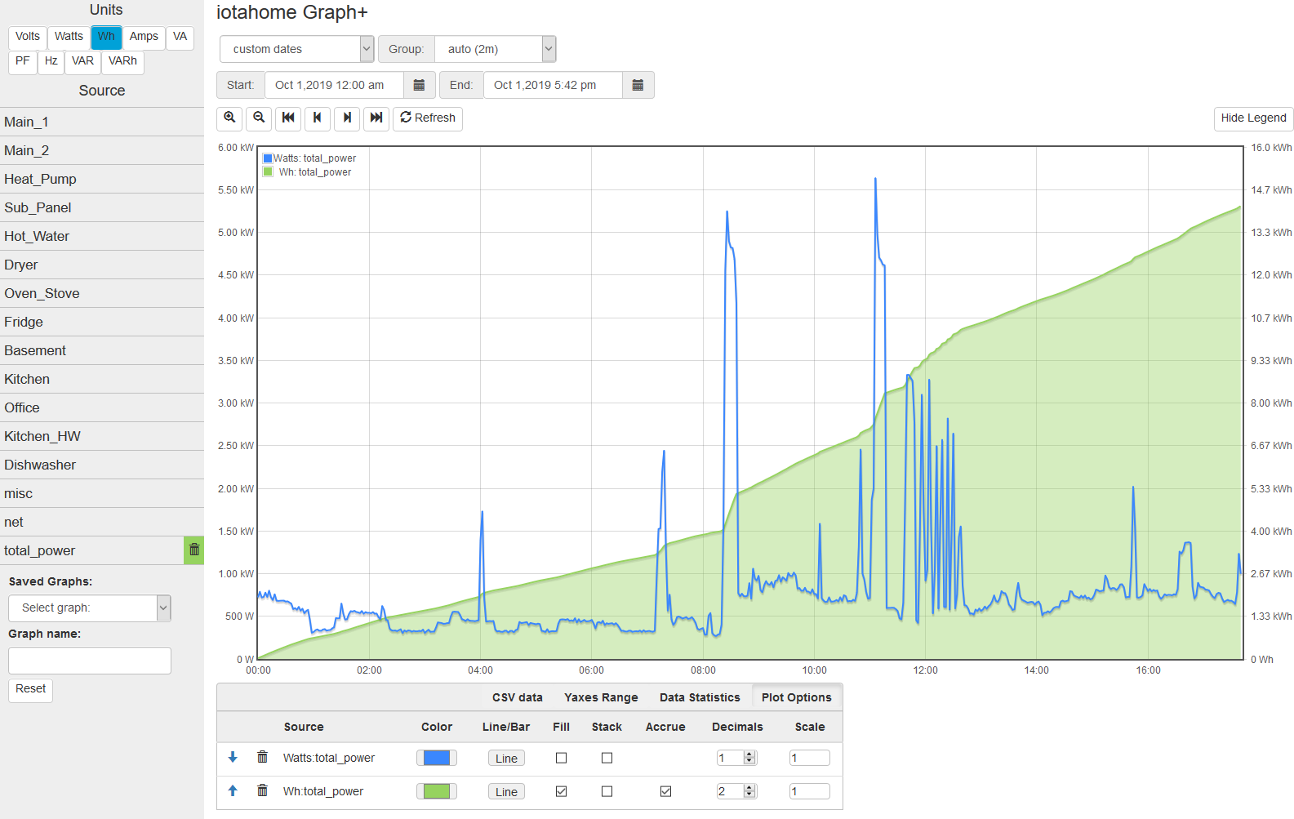
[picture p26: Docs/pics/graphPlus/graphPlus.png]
Graph+ image


Unit/Source selector
--------------------

So now lets break it down.  On the left is the "sidebar" where you select each of the 
measurements that you want to plot.
Every input (or output) can produce a variety of measurements.  
VTs measure Voltage and frequency(Hz), and CTs measure Watts, Watt-hours, Amps, VA,
and Power-Factor (PF).  So the first thing is to select the measurement you are interested in.
At the top are the unit selection buttons. Click on the particular unit you are interested in.

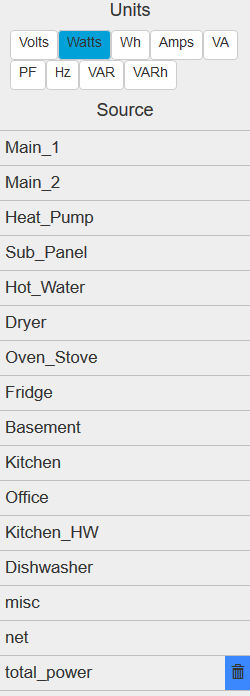
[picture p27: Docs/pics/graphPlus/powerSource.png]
CT sources


The Source list that appears below the unit selection will list all of the sources 
that can produce a measurement with the selected until.  
Basically Volts and Hz pertain to VT inputs and all other units pertain to inputs 
(or outputs) that are configured with CTs. 
The list will change immediately when a new unit is selected. 

On the right Watts are selected and this CarbixEnergyMonitor lists 15 sources that are configured
as power channels (CT inputs or CT based outputs). Note that the last entry shows a 
blue trash-can indicating that particular unit/source has been selected and is 
currently graphed.

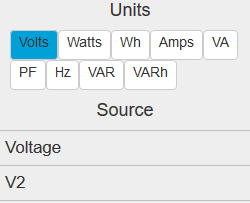
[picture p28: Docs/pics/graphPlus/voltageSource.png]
VT sources


To the left Volts are selected, so a different set of data sources corresponding to voltage
inputs (VTs) are listed.

Click on any of the individual sources in the list to add that data source to the graph, 
measured in the selected unit.  This combination is called a trace.  It will be assigned 
a distinguishing color and the list entry will now include a trash-can symbol with the 
assigned color as a background.  The trace should also appear on the graph within several seconds.  

While the list of sources may be the same for different units like Watts and Wh,
they only show active if they are being graphed in the currently selected unit.
In the case of the graph above, Total-Power is plotted as both Watts and Wh, so it
will appear as selected under both units, but note in the large picture above 
that the color is blue under the Watts unit, while it is green under the Wh units, 
indicating they are different traces.

One final note about the sidebar.  It will disappear when the screen size gets to be 
too narrow to accomodate it.  When that happens, it is replaced by a list icon at the 
top left of the main screen.  Pressing that will overlay the main body with the selection 
sidebar. An X on the sidebar is used to hide it again.

Time period selector  
-------------------------

Graph+ plots all selected traces over a single time period that is defined
and modified using the time period selection section. 
You can select one of the many pre-defined
relative time periods or specify absolute dates and times.
Once data has been plotted, the zoom/pan buttons can be used to modify the 
time-frame.  Graphs with relative time-periods ending in the present can be set to 
automatically refresh.

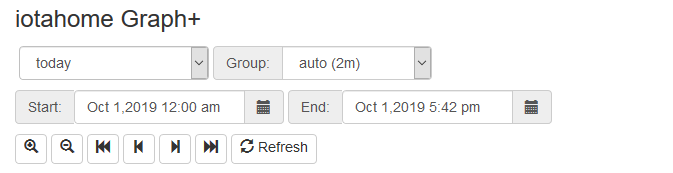
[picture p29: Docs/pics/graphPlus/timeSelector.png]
Time timeSelector


Period Selector
...............

This is where you specify an initial time period, and where you go to change it.
In the upper left is a dropdown selector that is used to specify common relative 
time periods.

Period list

For most analysis of recent activity, these selections should make things
quick and easy.  All of these predefined periods are relative to the current date/time.
So if you ask for today, you will get a plot of measurements from midnight to the 
current time.

Group Selector 
..............

CarbixEnergyMonitor records each measurement at 5 second intervals. That's 17,280
measurements per day. The graph size cannot possibly represent that, and it would take
a long time to query that amount of data.  Instead, CarbixEnergyMonitor can deliver either
the average value or net change of a measurement for any given interval.
So when plotting a day's worth of data, we ask for automatic grouping which results
in aggregating the data over 2 minutes in a 24 hour period.  If you were looking at
one hour or less, the grouping would be the highest resolution 5 seconds.

There are other choices when looking at longer time periods. Here we're plotting last month's 
usage and will group by day.  This will return the average or change in value for each of
the 28-31 days in the past month.  All units are averaged except Wh, which return the
total used in each grouping.  So in this case, there would be 28-31 data points plotted.

Group Selecting

It's important to note that when selecting grouping by day, week, month or year, you are
not just getting the nominal grouping of 24 hours, 168 hours, etc.  The selection process
recognizes daylight-time in determining hours and days, and recognizes day of week,
and month boundaries.

*   Weeks begin and end at 12:00am on Sunday.
*   Months begin and end at 12:00am on the 1st day of the month.
*   Years begin and end at 12:00am on Jan 1.

Custom Date Selection 
.....................

If the time period needed isn't covered in the selection list above, there are 
date pickers that can be used to choose specific start and end dates (and times).
If you click on these dates, a calendar will appear to select a start and/or 
end date and time.  When you change either of these dates, the period selector 
will automatically change to "custom dates" and the graph will be updated to span
the new date specification.

This is only one of several ways to manipulate custom dates. There are two other
ways to modify the dates bounding the current graph.  The most obvious is the 
zoom/scroll bar.

Zoom/Scroll bar

This bar works just as you think.

* Zoom (+) will zoom in 50% on the center of the graph.
* Zoom (-) will zoom out 100% on the center of the graph.
* Left Full (<<) Will shift the time into the past 100%, ending where it once began.
* Left Half (<) Will shift the time 50% into the past.
* Right Half (>) Will shift the time 50% into the future.
* Right Full (>>) Will shift the time 100% into the future, starting where it once ended.

There is one last way to modify graph period.  You can simply select a subset of 
the graph window holding down the left mouse button.  When you release it, the 
highlighted selection will become the new time period.

Screen Selection

Refresh/Freeze
..............

The Refresh Button button will immediately refresh the current plot.
If the time period of the current plot ends at the current time, 
as in the "Today", "Last 10 minutes", etc., the display 
will continue to refresh at the "interval" rate.  
For example if the auto interval is 2 minutes, it will continually refresh every 2 minutes.
You will know it is auto refresh mode because the Refresh button will change to
Freeze Button. If you click this button the auto refresh will stop and the button will
revert to the manual Refresh Button button.

The Refresh/Freeze state is retained when saving and subsequently restoring graphs.
This feature is useful when loading a saved graph as an embeded window where there are
no controls, allowing an auto refresh graph can be displayed in a frame.





Graph window
-------------

Once data sources are selected, the graph window comes to life.

Graph Window

In the upper left is the legend, a list of all of the unit/source combinations that are 
being plotted. The color of each trace matches the color used to designate 
the source selection and the color associated with the trace in the option table that
will be described later.

There is no notion of a left or right Y-axis selection.  
Each unit that is included in the plot is alternately placed on the left and right side 
of the plot automatically. 
You know which scale pertains to each trace because the scales contain the unit designation.  

Trace tables and options
------------------------

The last major section of the window is the options and information table area.  This is a 
multi-purpose area that displays different tables depending on the selection in the 
top row. There are four tables:

Options Table 
.............

Options Table

This table lists all of the traces selected for the current graph, and allows 
modifying the default settings for each trace.  Changing an option will have
an immediate effect on the graph.  There is no Save or Refresh required.

:Arrows:
  These sort arrows appear when there are two or more entries in the table.
  Use them to reorder the entries.  Primarily helpful when using Stacked traces.

:Trash: 
  Removes the trace from the graph and deselects from the source list.

:Color: 
  Selects an overide color.

:Line/Bar:
  Toggle between line or bar chart for this trace.

:Fill:
  Fill the area under the line or bar.

:Stack:
  Stack this trace above any other stacked traces appearing
  before it in this list.  You can change the position of a 
  trace (and so it's stack position) using the sort arrows 
  appearing at the beginning of each entry when two or more 
  traces are present.

:Accrue:
  This checkbox will appear on Wh traces and causes the Watt-hours
  to accrue in order to plot a running total.  Wh are accrued in the sample
  graph to illustrate this feature.

:Decimals:
  The number of decimal places to request and plot.  The default
  value is typically appropriate for the unit of measure, but 
  sometimes increasing the precision provides a more detailed representation.

:Scale:
  The values returned in the query will be muliplied by this scale factor.
  This will affect the values in the CSV table as well.

Statistics Table 
................

Statistics Table

This is a list the traces with useful statistics.

:Arrows:
  These sort arrows appear when there are two or more entries in the table.
  Use them to reorder the entries.  Primarily helpful when using Stacked traces.

:Trash: 
  Removes the trace from the graph and deselects from the source list.

:Quality:
  This indicates the number and percent of groups for which data was 
  available.  It is typically 100%, but could be less because of power 
  failures or malfunction during the period.  

:Min:
  The smallest group value graphed for this trace.

:Max:
   The largest group value graphed for this trace.

:Diff:
  Difference between Min and Max.

:Average:
  Mean value of all of the groups graphed for this trace. 
  Does not include null values.

:Sum:
    For Watt and Wh traces this is the total Wh for the period.

Yaxes Range Table 
.................

Yaxes Range Table

This list is used to modify the Yaxis range for each unit.  The default is "auto",
which works well to represent the full range of the data, however the Min and/or Max 
can be specified here to overide the auto default.  Once changed, the new limit will remain 
in effect until one of these things happens:

* The overide value is removed.
* A saved graph is loaded.
* The reset button is clicked.

Plot Range:
  The Yaxis range used in the current graph.

Data Range:
    The actual range of all of the traces using this unit.

Min:
    The lower bound to be used in subsequent graphs, or blank for auto assignment.

Max:
    The upper bound to be used in subsequent graphs, or blank for auto assignment.

CSV Data 
........

CSV Data area

This is a comma-separated-values listing of all of the data used in the current graph.
The first column is the time, subsequent columns are the group values for the
traces in the order that they are listed in the options or statistics tables.

There are a couple of options available:

Time Format:
    * Date-time string - selects a date and time format acceptable to spreadsheets.
    * Seconds-from-start - selects a count of seconds from the start time.
    * Unix-time - selects the count of seconds from Jan 1, 1970 UTC.

Null Values:
    * Show - include missing or invalid lines with "null" as a value.
    * Remove line - Where a line has a null value, remove the entire line from the display.

Copy:
    Copy the contents of the CSV table to the clipboard.

Download:
    Download the CSV data as a file.
    
Saving Graphs
--------------

Graph+ is great for ad-hoc queries, but it can take some time to fine-tune a 
busy graph, and it recreating it weekly or monthly can get old.  This is where 
the ability to save a set of graph specification comes in handy.

At the bottom of the sidebar you can save and reload any number of graphs.
Each graph is saved in the CarbixEnergyMonitor, so it doesn't matter if you use a different
browser or device to recall them, they will always be there.

Saved Graphs

Once you have a graph that you like, enter a description in the *Graph name:* box. 
The **save** button will appear.  Click it. The graph has been saved. Click the 
*Saved Graphs:* selector and a list of all of the saved graphs will appear.
Click any selection and Graph+ will load that graph specification.

Saveds Monthly Wh

This is a graph of total monthly kWh to date.  Once loaded, I can do a lot with it:

* Change group to Weekly to see it by week.
* Change the period to last-year or anything else.
* Show the CSV table to see list of usage by month.
* Add traces for particular circuits, stacking if appropriate, to see a breakdown.
* Move the data to a spreadsheet to apply your tariff and convert to cost.

Note that you are saving the graph *specification*, not the actual graph.  If you
save a graph of yesterday and reload it tomorrow, it will plot today. If you want to
save a static graph, select the *custom dates* period at the top before saving.

Whenever a saved graph name is in the *Graph name:* box, the **Delete** key will be 
available. To change a graph specification, simply load it, make the changes and save 
it again.

Running Directly with URL
-------------------------

Graph+ can be loaded directly from the CarbixEnergyMonitor's web server using the URL

http://carbixenergymonitor.local/graph2.htm [?graph=savedgraph [&embed] ]

Substitute your local hostname/IP address if different.

graph=
......

Optional query parameter to specify a saved graph that is to be loaded initially.

embed
......

Causes Graph+ to display only the plot window of the selected graph. 
If the saved graph has refresh enabled, the plot will refresh at the 
active interval.

Reset
-----
Sometimes you just want to start over with a clean slate like the app was just loaded.

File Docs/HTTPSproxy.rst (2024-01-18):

==================
HTTPS Proxy Server
==================

Like many IoT devices, CarbixEnergyMonitor does not have the resources to communicate
over the internet using secure TLS. While the local LAN can be relatively secure,
data uploaded to internet based servers is transmitted in plaintext and
vulnerable.  One exception is the Emoncms web service where a protocol
to authenticate and encrypt communications is available.

Some external services, such as influxCloud, require TLS (HTTPS) be used
in all communications.  CarbixEnergyMonitor can use a simple proxy server on the local
LAN to overcome this limitation and forward internet communications using HTTPS.

NGINX (engine-x) is an open-source web-server that can be hosted on a variety
of inexpensive processors.  The ubiquitous RaspberryPi being a simple and 
inexpensive favorite.  Once setup, you only need to set the URL of the 
proxy server into CarbixEnergyMonitor, and it will be used to communicate with any
uploader where the URL of the service is specified as HTTPS:// method.

Setup up NGINX on a RPi
-------------------------

Rather than reinvent the wheel, this section will lean heavily on existing webtutorials to
setup a RPi based NGINX proxy.  Many will already have an RPi or other Linux based
resource on their LAN and can host NGINX there.

An RPi 3 Model B or better is recommended. With a case, SDcard and power supply the cost 
is usually less than $50 US. There are many tutorials for setting up the Basic RPi
with the latest software release.  Rather than post a link that may get stale, 
I'll leave it to the reader to search the internet for one that suits their
capabilities.

Once the basic system is up and running, it's easy to add NGINX.  Simply follow this tutorial_
from the RaspberryPi folks.

.. _tutorial: https://www.raspberrypi.org/documentation/remote-access/web-server/nginx.md

Add the HTTPSproxy location
------------------------------

Whether you decided to setup a RPi with NGINX or you installed NGINX on another platform,
all that is left is to add the Location configuration for the HTTPS proxy.

Download the HTTPSproxy location from the IoTaWatt
server to the NGINX configuration using the command:

    ``sudo wget -P /etc/nginx/sites-enabled https://iotawatt.com/download/HTTPSproxy``

Then reload the NGINX configuration using the command:

    ``sudo nginx -s reload``

Configure the proxy in CarbixEnergyMonitor
-------------------------------

Using a fixed IP address for the NGINX host, setup it's address in CarbixEnergyMonitor.
Select |setup| then  from the dropdown.
Add the URL with port :9000 and press **Setup button**.







**HTTPSproxy Setup**

Using the HTTPS proxy
---------------------

Once the HTTPS proxy address is specified, using it is easy.
PVoutput will automatically start to use HTTPS.
For influx or Emoncms uploaders, simply change the server
URL method to HTTPS://.

**server URL example**

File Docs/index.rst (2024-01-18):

======================
CarbixEnergyMonitor documentation
======================

..  toctree::
    :maxdepth: 2
    :caption: Contents:

    Quickstart <quickstart>
    Installation <installation>
    Connecting to WiFi <connectWiFi>
    Device Configuration <devConfig>
    VT Configuration <VTconfig>
    CT Configuration <CTconfig>
    Status Display <status>
    Outputs <outputs.rst>
    Integrators <integrators>
    Uploaders <uploaders>
    Configure PVoutput <PVoutput>
    Configure Emoncms <Emoncms>
    Configure influxDB <influxDB>
    Home Assistant <homeAssistant>
    Setting up Passwords <passConfig>
    Three-phase power <threePhase>
    CT Basics <CTbasics>
    Split-phase power <split-phase.rst>
    Data Visualization <dataVisualization>
    Graph+ <graphPlus>
    Original Graph <originalGraph>
    File Manager and Editor <fileManager>
    Query API <query.rst>
    HTTPS Proxy Server <HTTPSproxy.rst>
    Message Log <messageLog>
    Troubleshooting <troubleshooting>
    Accessing carbixenergymonitor.local <dotlocal>

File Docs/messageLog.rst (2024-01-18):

===========
Message Log
===========
The message log is the CarbixEnergyMonitor's Diary.
It makes notes about various events that occur, 
both ordinary and unusual. These messages can be helpful in 
understanding what is happening with the device, 
or to provide insight into why something doesn't 
appear to be working as it should.

The primary method of accessed the message log is 
by hovering over the Tools main menu button and clicking 
the Message Log button. 
The config utility will cause your browser to download 
and display the most recent 10000 characters in the log. 
You can access the entire log by using the File Manager 
app to download the file /carbixenergymonitor/carbixmsgs.txt and
viewing with a text file editor.

With the exception of the first messages after startup, 
all of the messages in the log will have a date and time stamp. 
Messages issued by one of the CarbixEnergyMonitor Services will begin
with the name of the service followed by a colon, 
as in this message issued from the datalog Service 
indicating it has successfully started.

::

    12/23/17 21:57:06 dataLog: service started.

While it would be impossible to maintain a list of all 
of the possible messages, 
the messages issued at startup are pretty straightforward 
and provide a lot of information.

::

    ** Restart **

    SD initialized.
    1/08/19 19:39:43z Real Time Clock is running. Unix time 1546976383
    1/08/19 19:39:43z Power failure detected.
    1/08/19 19:39:43z Reset reason: External System
    1/08/19 19:39:43z ESP8266 ChipID: 427289
    1/08/19 19:39:43z CarbixEnergyMonitor revision 4.9, firmware version 02_03_20
    1/08/19 19:39:43z SPIFFS mounted.
    1/08/19 14:39:44 Local time zone: -5:00
    1/08/19 14:39:44 Using Daylight Saving Time (BST) when in effect.
    1/08/19 14:39:44 device name: CarbixEnergyMonitor
    1/08/19 14:39:47 Connecting with WiFiManager.
    1/08/19 14:39:53 MDNS responder started for hostname CarbixEnergyMonitor
    1/08/19 14:39:53 LLMNR responder started for hostname CarbixEnergyMonitor
    1/08/19 14:39:53 HTTP server started
    1/08/19 14:39:53 WiFi connected. SSID=flyaway, IP=192.168.1.102, channel=1, RSSI -69db
    1/08/19 14:39:53 timeSync: service started.
    1/08/19 14:39:56 statService: started.
    1/08/19 14:39:56 Updater: service started. Auto-update class is BETA
    1/08/19 14:39:57 dataLog: service started.
    1/08/19 14:39:57 dataLog: Last log entry 01/08/19 14:39:35
    1/08/19 14:39:57 historyLog: service started.
    1/08/19 14:39:57 historyLog: Last log entry 01/08/19 14:39:00
    1/08/19 14:39:58 influxDB: started, url=192.168.1.101:8086, db=carbixenergymonitor, interval=10
    1/08/19 14:39:58 Updater: Auto-update is current for class BETA.
    1/08/19 14:39:58 influxDB: Start posting at 01/08/19 14:39:40

Some things to look for:
::
    Real Time Clock is running. Unix time 1546976383

Except for initial setup, the RTC should always be running.
If it is not, suspect the battery needs replacement.
::
    Power failure detected.

This indicates that power interrupted prior to the restart.
::
    Reset reason: External System

This is the reason for the restart.
External System is a normal cause. Reasons like WDT and 
Exception indicate program faults and, if frequent, 
should be posted to the support forum.
::
    CarbixEnergyMonitor revision 4.9, firmware version 02_03_20

The hardware and firmware versions.  Good to know if things
go wrong, and also useful toget the corresponding version
of this documentation.
::
    Local time zone: -5:00

The local time zone specified in you config file.
This message and all subsequent messages should
be timestamped with local-time as opposed to UTC
which was indicated in prior messages with by the suffix 'z'.
::
    device name: CarbixEnergyMonitor

This is the external name of the unit.  It will
be used as the hostname when connecting to
WiFi and it is the name that you must use to 
access the device as in http://carbixenergymonitor.local.
::
    WiFi connected. SSID=flyaway, IP=192.168.1.102, channel=1, RSSI -69db

Indicates connection to WiFi and the IP address 
assigned. The RSSI is an indication of WiFi signal strength.
A good number would be between -50 and -78 or so.
If you are having WiFi problems, this metric along with
the channel number can be helpful in resolving.
::
    timeSync: service started.

All of the regular services will log their startup.
Some will also provide additional information 
about their configuration or state. All messages 
from system services begin with the name of the service
followed by a colon.

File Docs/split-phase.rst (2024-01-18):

========================
Split-Phase Installation
========================

This chapter assumes the reader has read the `CT Basics <CTbasics.html>`_ section.

--------------------
What is split-phase?
--------------------
Worldwide, virtually all of the residential power delivered to residential homes
is 230V-240V single phase.
In North America, the single-phase 240V supply is split so that there are two 120V
legs that are typically used for lighting and light-duty appliances.
To learn more see the
`Split-Phase Wiki <https://en.wikipedia.org/wiki/Split-phase_electric_power>`_.

------------------------
Split-phase load centers
------------------------

Split-phase load center

    Maybe neater than normal load center

A typical split-phase load center has two Main circuit breakers, one for each of the two
"legs" coming from the service entrance.  There is also a third neutral wire that is
directly connected to the neutral bus - a long bar with holes and screws to connect
conductors.  Another ground bus is provided which is connected to a reliable local
earth connection like a ground stake.  
In most entrance panels, but not sub-panels, the neutral and ground busses are "bonded" (connected together).

The service is typically described in terms of the amperage rating of the Mains 
circuit breakers or fuses.  Most common are "100A service" and "200A service".

See the North America section of this Load-Center Wiki_.
to see how the split-phases correspond to alternating breaker rows. 

.. _Wiki: https://en.wikipedia.org/wiki/Distribution_board

----------------------
Monitoring split phase
----------------------
When monitoring a circuit in a split phase service, it's helpful to
recognize exactly which of the mains circuits it is utilizing.
There are three possibilities:

............
120V phase A
............ 
    These circuits are two conductor (plus ground) and typically use
    a black conductor connected to the circuit breaker and a white
    conductor connected to the neutral bus. As described in the Wiki_,
    circuit breakers in odd rows will be on phase A.
    Odd rows include breakers numbered [1,2] [5,6] [9,10]..etc.

............
120V phase B
............ 
    Same as above, except circuit breakers will be in the even rows
    with breakers numbered [3,4] [7,8] [11,12]... etc.

....
240V
....
    These circuits are typically larger appliances like Hot-Water,
    Range, Pumps, Electric Heat, Dryers, Heat-pumps, sub-panels, 
    and Air-conditioners. They use two circuit breakers in adjascent
    rows, so one of the breakers is on phase A and the other is on phase B.
    
    As explained in the `CT Basics <CTbasics.html>`_ section, 240V 
    loads can be two-wire or three-wire.

    Two-wire loads typically use two conductor cable with the white and 
    black conductors connected to the two circuit-breakers.  For these 
    circuits, a single CT can be placed on either one of the two conductors
    and the "double" box checked to indicate to CarbixEnergyMonitor that the voltage
    is doubled to 240V. Orientation of the CT is dependent on the row that
    the CT is associated with.

    Three-wire loads typically use three conductor cable with black, red,
    and white conductors.  The red and black are connected to the two 
    breakers and the white is connected to neutral.  These loads must 
    be measured with two CTs, one on the red and one on the black, or 
    by passing the two conductors through one CT in opposite directions 
    so that the resulting orientation of the CT is correct for the row
    of the breaker that each conductor is connected to. An illustration
    can be found in the `CT Basics <CTbasics.html>`_ section.

-----------------
Voltage Reference
-----------------
The voltage between the two mains conductors is nominally 240V.
That is broken down into two 120V potentials between each of the
Mains and the neutral, but unless they are in perfect balance,
there will always be a difference in voltage between the two phases.
That said, the difference in most situations is practically negligible
and the sum of the two will always equal the voltage between the two Mains.

This is an important point, because in order to measure real-power,
what your meter measures and what you pay for, it's necessary to also have
a reference voltage on that circuit.

CarbixEnergyMonitor supports multiple voltage references, but as a practical
matter, you only need one to measure any of the three circuits 
described above.

The simplest and most effective reference is a 120V wall
transformer connected to an ordinary 120V plug as close to the 
load center as possible. That will provide a reference for the
phase it is plugged into, *and a reference that is the exact 
opposite of the other phase*, or to put it another way, 
the *reverse* of the other phase. 

--------------------
Mains CT orientation
--------------------
The first CTs to be installed should be the Mains.  

    **As mentioned in multiple discussions, this is a job for someone 
    familiar with the working with live, partially exposed electrical
    wiring and familiar with all of the risk factors.
    An electrician is recommended.**

Because each of the Mains is on a different phase, 
and we are using the same voltage reference for both phases, we need
to reverse one of them so that the current it measures aligns with
the reversed voltage reference.  So which one?  The answer is that because
the wall transformer plug is not polarized as well as other uncontrolled
factors, we don't know yet.  

So what we do is just install
the CTs with opposite orientation, `configure them <CTconfig.html>`_, and 
look at the status display of the CarbixEnergyMonitor.  If reversed,
they will show a ↺ symbol. To correct this, you can do one of two things.

- Reverse the wall transformer in its socket.
- Click the "reverse" box in the VT configuration menu.

Now, the two Mains inputs should show the Watts for each Main and
no reverse ↺.

-------------------
Load CT orientation
-------------------

First, it's important to note that the only consequence of installing 
a load CT backward is that it
will show a ↺ symbol next to the input in the status display. 
This indicates that CarbixEnergyMonitor has recognized that the voltage and
current are opposite and is producing the correct measurement
by reversing the output numerically.  There is no error attributable
to this correction. If the ↺ symbol doesn't bother you, you can place the CTs without
regard for phase.

Another approach is to simply install the CTs without regard for phase orientation
and then simply check the "reverse" box for any inputs that show the ↺ symbol
in the status display or physically reverse those CTs in the load center.

To install with correct orientation initially, the easiest method is to install
one CT on an active circuit and note if the ↺ symbol appears in the status
display.  If so, reverse that CT.  Now note which way the correctly oriented CT is
installed and whether its row is even or odd.

If it's an even row, all of the CTs that you install on even row circuit-breakers
should be installed with the same orientation and the odd row circuit breakers with
the opposite orientation.

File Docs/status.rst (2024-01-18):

=====================
Device Status Display
=====================

Overview
--------

The configuration app can provide a continuously 
updating display of many aspects of CarbixEnergyMonitor operation.
The output is organized into expandable tabs containing 
various categories of information. 
Simply click the **Status button** button.



Status Display

The initial display will always have the Inputs/Outputs Status tab expanded.  
Simply clicking on that tab, or any of the other tabs, 
will toggle them between expanded and collapsed. 
The various tabs as of this writing are detailed as follows:

Inputs/Outputs
--------------

Inputs/Outputs Display

This tab lists all of the configured input channels on the left, 
and all of the defined outputs on the right. 
Both columns show the current measurement value. 
Input channels values are in Watts or Volts for CT and VT 
channels respectively.  
CT channels also will display the power-factor (PF) 
when the power is sufficient to develop that reliably.
Output channel values are in the units configured.  
They may be Volts, Watts, Amps, VA, Hz, or PF.
All values are damped, which is to say they are averaged 
with an exponential decay 
algorithm so that they will not jump around excessively.  
That said, the algorithm does respond to large changes quickly and 
settles in on small changes within a few seconds.

Statistics
----------

Statistics Display

The statistics tab provides insight into the current operation of the 
CarbixEnergyMonitor with the following information:
    
    * **Firmware version:** Release of CarbixEnergyMonitor firmware.
    * **Running Time:** Since last restart.
    * **free Heap:** An indication of the working memory 
      available to the firmware.
    * **Samples per AC cycle:** Average samples CarbixEnergyMonitor is
      achieving when sampling a channel.
    * **AC cycles sampled/second:** Average number of channels 
      that are measured per second.
    * **Hz:** Current AC frequency.

Web Servers
-----------

Web Servers Display

These tabs appear when `data upload <webServer.html>`_ to PVoutput, 
Emoncms, influxDB has been configured.  
They indicate the state of the services that are responsible for 
sending the data to the respective server.

    **Start/Stop button:**  Use to pause and resume uploading data.
    This button works asynchronously, and may take awhile 
    to perform the action. Pressing multiple time may cause 
    it to go out of sync.  Use it carefully.

    **Running/Stopped:** The current state of the service.

    **Last Update:** Data/time of the last data sent to the server.

Data Logs
---------

Data Logs Display

This tab displays the date/time of the first and last entry 
in both the Current Log and the History Log.  
These dates may take a few seconds to become accurate as the CarbixEnergyMonitor starts.
The History Log should begin from the data/time when the 
CarbixEnergyMonitor was first installed,
or when the History log was last created after being deleted.  
It should increment every minute while the unit is running.

The Current Log contains up to a year's worth of data, 
and maintains that data at 5 second resolution.  
When the approximate year capacity is reached, it will "wrap" back around 
and begin writing over the oldest entries.  
Newer logs will show the same start date as the History Log.  
As the log ages and reaches capacity, the start date/time 
will advance at 5 second intervals along with the 
ending date/time.

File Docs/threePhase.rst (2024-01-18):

=============================
Three-phase Power
=============================

CarbixEnergyMonitor has the capability to measure power in polyphase systems.
In the interest of keeping the user interface simple for the majority 
of users who have single phase power, the details are disguised and/or hidden
until needed. There has been a lot of interest in using CarbixEnergyMonitor
for three-phase monitoring, particularly in three phase countries like
Australia and Germany. For home energy monitoring, the *derived reference*
method has been overwhelmingly popular.

This chapter explains two methods for measuring a so calld "four wire"
or "wye" system, by far the most common implementation of three-phase.
CarbixEnergyMonitor can also be used with "three wire" or "delta" systems using
different methods.

As explained in the introductory single phase section, 
a voltage reference is needed to measure real power. 
The challenge with three-phase power is to obtain 
three different voltage/phase reference signals. 
CarbixEnergyMonitor can do this by two different methods:

    **Derived Reference** uses a single voltage transformer 
    and *derives* a reference voltage/phase for the other two 
    phases by numerically shifting the phase of the single 
    reference by 120° or 240°. The primary advantage is 
    low cost and convenience of installation. 
    The disadvantage is that large variations in voltage 
    between phases may result in decreased accuracy.

    **Direct Reference** uses three discrete voltage transformers 
    or VTs, each one plugged into a circuit on a different phase. 
    The primary advantage is voltage accuracy, while the 
    disadvantages are that the extra VTs add cost, use 
    two of the 14 inputs for the additional VTs, and require plugs on each phase 
    in proximity to the CarbixEnergyMonitor.
    
Configuring Derived Reference
-----------------------------

Derived reference uses a single voltage reference VT and `derives`
the other two signals by phase-shifting. 
While not as exact as direct reference, it produces very good results 
and is the overwhelming choice of residential three-phase users.

This chapter explains how to configure CarbixEnergyMonitor to
use "Derived Reference". A word of caution:

    *There are 36 different combinations of CT orientation
    and phase assignment.  Only one of them is correct.  This simple 
    procedure, when followed methodically, will avoid the common pitfalls suffered
    by those who try to stumble on the solution.*

Start by getting the mains installed and configured correctly.  Everything will
fall together from there.

Install and Configure the CTs
^^^^^^^^^^^^^^^^^^^^^^^^^^^^^

Install the three mains CTs on the incoming three-phase 
lines. If the CTs have an arrow, install them so that the
arrow points toward the mains breaker. This is very important:

    *Be sure to orient all of the CTs the same way 
    with respect to source and load. By doing so, you 
    reduce the number of possible incorrect solutions to 5.* 

Connect the CTs to the CarbixEnergyMonitor and use the `inputs` setup to
set the CT model. Check the *allow negative values* box for each.

Configure the VT
^^^^^^^^^^^^^^^^

Set up your CarbixEnergyMonitor with the voltage reference VT on whatever
phase of the three-phase is convenient. We will call that phase
A. This is important:

    *However you identify your physical phases, CarbixEnergyMonitor always
    identifies the phase that the VT is connected to as phase A.*

The other two `derived` phases will be phase B and phase C. 
It doesn't matter which of the physical phases
your VT is connected to. Your starting point is always A.

There are color coding schemes for the phases, but they vary widely,
so no attempt will be made to reconcile these instructions with
colors or local alphanumerical designations.  If your system uses
designations A, B and C for the phases, it would avoid confusion if
the VT could be plugged into your phase A. 
The good news is that you really don't have to know what 
any of the phases are to complete this setup.

Identify Phase A 
^^^^^^^^^^^^^^^^

For this step, you will need a significant plug-in load, such as 
a hair dryer, toaster, or possibly a high wattage incandescent light.
As previously stated, Phase A is the phase that the VT is connected to.
To identify that phase, connect the load to the same
outlet as the VT.  You may need to temporarily employ a power strip.

While watching the power draw of the three mains on the CarbixEnergyMonitor status display,
switch on the load.  One of the three mains should change.  To be sure, 
switch the load off, then back on several times. The status display is damped, 
so it takes several seconds to settle on the new value. 
This is phase A.

Note by how much phase A changes when you switch on the load.  You will need
to know that in the next step.  If phase A is negative and decreases when you 
switch on the load, you can either:

        * Reverse the VT in it's socket - or -
        * Check the `reverse` box for **all three** of the mains CTs.

    *There is now only one correct and one incorrect solution.*

Identify the Other Two Phases
^^^^^^^^^^^^^^^^^^^^^^^^^^^^^

At the bottom of the input configuration menu, 
Check `Enable derived three-phase`.
The configured input channels will now have "phase:A" 
appended to their descriptions.

**Derived Three-phase Inputs**

You know which of the three is the `real` phase A. 
Edit the other two and assign to phase B.

**Derived Three-phase Selection**

Locate another outlet that you know or suspect is not on phase A.
Connect the load and cycle as before.  Notice which main changes.
If it's A, try other outlets until one of the other two phases changes
with the load.

Note by how much the main changes when you cycled the load.  If it's the
same as it was on phase A, then this is phase B, change the remaining 
main to phase C.

If it is significantly less, closer to half the change that you noted on phase A,
then this is phase C. Change it to phase C leaving the remaining phase as B.

Test the load again.  It should increase by the same amount as when it was 
on phase A.

The derived configuration is now complete. Jump to 
`Branch Circuits`_ below.

Configuring Direct Reference
----------------------------

Connecting additional VTs
^^^^^^^^^^^^^^^^^^^^^^^^^

To use Direct Reference three-phase power measurement, 
it's necessary to install two additional 
VTs (total of three), and to plug each of them into a 
receptacle that is supplied by a unique phase. 

Version 5 of CarbixEnergyMonitor has plugs to connect the additional VTs.
This tutorial will assume you have the version 5
CarbixEnergyMonitor.

The additional VTs will plug into two sockets at the rear
of the unit.  They are labelled VT-13 and VT-14.
When these are used, the standard channel 13 and 14
jacks cannot not be used for CTs.

**V5 VT Inputs**

Configuring the voltage inputs
^^^^^^^^^^^^^^^^^^^^^^^^^^^^^^

Now the additional VTs can be configured and calibrated. 
Do this in the same way that the first VT was configured. 
Click the channel number, click "VT" then specify the model. 
You can also calibrate the voltage if desired. 
It's not necessary that the VTs be plugged into their 
eventual phase to calibrate. 
If you have two outlets on any of the phases, 
use those to plug in each VT in turn along with a voltage 
reference while you calibrate. Once calibrated, 
the VTs can be moved to the appropriate phase/socket.

**Add Additional VTs**

Name each of the phases to uniquely identify each reference. 
You can use phase_A, phase_B etc., 
or maybe use the color coding of your system to be more descriptive - 
voltage_red, voltage_black, voltage_blue (US).

Configuring the CTs
^^^^^^^^^^^^^^^^^^^

Now add your mains CTs. 
The twist here is that because more than one VT is configured, 
an additional selection box is displayed to specify 
which VT is associated with the phase of that particular CT.

**Select Reference VT**

Set associated Vref in each CT

**Select Reference VT**

Branch Circuits
---------------

Like the mains, all of the branch circuit CT should be oriented the same way.
In panels that observe a color convention for the different phases, it 
should be easy to determine the main, and thus the phase, associated with
each branch circuit.

Where the wires are not coded, it will be necessary to trace them back to the main,
or if it's a single-phase branch, cycle it and see which main responds.

North American three-phase panels look very similar to split-phase panels except
rather than alternate between two split-phases, each side alternates through 
the three phases.

If using `derived reference`, simply set the corresponding mains phase in 
each branch CT configuration.  If using `direct reference` set the corresponding 
VT in each branch CT.

Reporting Power
---------------

When all of the VTs and CTs are configured, 
there are several ways to view the power used. 
For circuits and/or loads that use only one phase, 
the power value displayed for that channel should be correct as is. 
If there are devices that use two or three of the phases, 
you must add the power from each of those phases to get total power. 
For each such device, define an output channel and use the calculator 
to specify which channels to add. 
If you are reporting the data to a server, 
the data can be tailored with the calculator to send the single 
combined aggregate power for those devices.

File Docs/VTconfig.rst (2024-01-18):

=================================
Voltage Transformer Configuration
=================================

A prime component of electrical power is voltage.
The AC line frequency is the heartbeat of the CarbixEnergyMonitor.
A reliable and accurate AC voltage reference is very important.
You should have installed the device with a 9 Volt AC voltage reference
transformer (VT) plugged into the channel zero power jack.
If your initial configuration has this channel pre-configured,
your LED will be glowing green because it's rhythmically sampling that voltage.

Various transformer models produce different voltages,
and it's important to insure that the VT specified 
matches the model that you have installed.
To do this, select the inputs button in the Setup dropdown menu.

Setup Inputs List

A list of all of the inputs will be displayed.
The first entry will be input 0 and a default VT should be configured.
Check to see if it's the same as your VT model.
It's OK to unplug the VT to check the model number printed on it.

If your VT model doesn't match the model that is configured, you can easily change it.
Click on the input channel 0 button on the left.

Configure VT Menu

As you can see, the display changes to reveal the details of the input_0 configuration.

Select VT Image

VT Model Selection
------------------
If your make and model is listed, select it from the list.
At this point, you can just click **Save** and the standard 
calibration for your VT will be used.
That calibration should be good for all but the most discerning users.
If you have access to a good voltmeter or other reliable 
high accuracy voltage reference,
you can fine tune with the calibration procedure below, but for average users,
you should be good to go on to the next step Adding Power Channel CTs

If your VT wasn't listed in the dropdown above,
the generic entry is a reasonable starting point 
that will get you in the ball park for your 9-12Vac adapter.
If your country is 230V or 240V select "generic240V". 
Now you must perform the `Voltage Calibration`_  procedure below.

TDC DA-10-09 model ambiguity
~~~~~~~~~~~~~~~~~~~~~~~~~~~~

There are two different voltage transformers available with the model designation TDC DA-10-09.
These models are quite different and need to be properly configured.

TDC DA-10-09

    use model: TDC DA-10-09

TDC DA-10-09-E6

    use model: TDC DA-10-09-E6

Voltage Calibration
-------------------

Again, if you are using one of the standard voltage transformers from
the tables, this step is optional. 
Repeated random tests on the standard US and
Euro transformers yield excellent calibration right out of the box.

You will need a halfway decent voltage reference for this step.
If you don't have a decent true RMS voltmeter and can't borrow one, 
go out and get a Kill-a-Watt.
They cost less than $20 (some libraries lend them out) and 
I've found their voltage readings are usually accurate.

click **Calibrate**

Calibrate VT Menu

Follow the instructions on the page. Increase or decrease the "cal" factor
until the voltage shown settles down and is a pretty 
good match with your reference meter.
It's not possible to match exactly. 0.2V in a 
120V installation is 0.2% variation.
A good meter accuracy is 1% at best. Just try to get the 
two to dwell around the same set of fractional digits.

As instructed on the page, click save to record the calibration factor.
The new calibration factor will take effect immediately.
Click the Status menu button to display the voltage:

VT Status

Wait a few seconds then check that the voltage 
displayed is still in the ball park.
If not, repeat the calibration procedure.

Once calibration is complete and verified,
you will not need to do it again unless you change your VT transformer.
The CarbixEnergyMonitor has a very accurate internal calibration reference and will maintain
its accuracy indefinitely. You should have no further need for the voltmeter.

Now the device is ready for the next 
step `Configuring Power Channel CTs <CTconfig.html>`_





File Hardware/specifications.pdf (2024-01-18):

IotaWatt, inc.

IotaWatt model 4 Specifications
effective August 1, 2017
Size (HxWxL) | 27x85x125 mm / 1.06x3.35x4.92 in
Weight | 140 g / 4.9 oz

Power
Nominal Voltage | 5 vdc
Connector | micro USB
AC Reference Input | 1
Nominal Voltage | 9 to 12 VAC
Connector | 5.5mm x 2mm
Resistance | 13k ohms
AC voltage/power inputs | 14
Nominal voltage | 0 to 1 VAC rms
Connector | 3.5mm stereo jack
Resistance | 24 ohms

Temperature
Operating | -10 to 50 ºC / 15 to 122 ºF
Storage | -20 to 60 ºC / -4 to 140 ºF

Battery
Type | CR1220
Nominal Voltage | 3V

Storage
Type | Micro SDHC
Capacity | 8 GB min
WiFi | IEEE 802.11 b/g/n – 2.4gHz

PO Box 1679, Wolfeboro, NH 03894

IotaWatt, inc.

Tolerances:

USB Power
Voltage | 5 VDC +/- 5%
Ripple and Noise | 300 mV p-p max
Power | <1W

AC Reference Input
Absolute Maximum | 15 VAC rms / 21 VAC p-p

Voltage/Power inputs
Absolute Maximum | 1.1 VAC rms / 1.5 VAC p-p
| 45maAC rms

PO Box 1679, Wolfeboro, NH 03894

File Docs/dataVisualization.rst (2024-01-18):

=================================
Data Visualization
=================================

CarbixEnergyMonitor is capable of storing ten years or more of high resolution data.
An integrated web-server provides access to that data using a versatile 
query/graph application called Graph+ and also provides a RESTful data query 
facility capable of producing JSON or CSV formatted downloads.

You can also upload your data to InfluxDB, PVoutput or Emoncms.org providing 
a variety of alternative ways to organize and view your voltage,
power and energy use. The servers can be fast and accessible 
from any place where there is internet connectivity. 
But there are some circumstances under which you may prefer to 
access your data directly from the CarbixEnergyMonitor:

*   You prefer the simplicity and power of the local graphic viewer.
*   You are not using Emoncms or influxDB to save your data.
*   You require finer resolution than is used in your Emoncms feeds.
*   You need to see data that is collected by CarbixEnergyMonitor but is not being
    uploaded to your cloud service.

There are two graphing packages available with the current release:

`Graph+ <graphPlus.html>`_
--------------------------------------

This latest graphic viewer unlocks virtually all of the data in the datalog. You can
graph all of the metrics associated with each input or output, including Volts,
Watts, Wh, Amps, VA, PF and Hz.

There are selectable predefined time-periods like "Today", "Yesterday", "Last Week"
and "Last Month", and a calendar interface that can be used to select custom date/time
bounds. Data can be grouped by hour, day, week or month. The CarbixEnergyMonitor query recognizes
week and month boundaries and daylight-time changes.

`Original Graph <originalGraph.html>`_
--------------------------------------

The graph program provided in the initial releases through 02_03_02 is still
supported and available for those who may have become comfortable with it and
whose capabilities are adequate for your needs.  It remains as a menu pick under
Data tab.

The new Graphic Viewer is a superset of the functions of the Original Graph, so
this feature should be considered depricated and may be removed in a future release.

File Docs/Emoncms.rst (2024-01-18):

=======
Emoncms
=======

Setup Emoncms
-------------

Emoncms is an open-source system that stores time-series 
data and has multiple reporting apps developed by the authors 
as well as apps contributed by users in the open community. 
The graph application used locally by CarbixEnergyMonitor is a derivitive
of that effort.

For a nominal fee you can use the managed
enterprise version of Emoncms at Emoncms.org or you can 
install the software on your own machine, including 
a RPi, and run a local instance for free.

Configuring an CarbixEnergyMonitor to upload to Emoncms is easy.
First, go to Emoncms.org and establish an account, or 
install the software on your server and setup an account. 
There is a nominal fee to use Emoncms.org that should amount 
to a few dollars per month for a typical CarbixEnergyMonitor user.

Configure CarbixEnergyMonitor
------------------

After establishing an account, run the CarbixEnergyMonitor
configuration application, hover over **Setup button** and click 
**Web Server** from the dropdown menu.

**Select Uploaders**

Choose Emoncms.

**Select Emoncms**

Here you will specify the URL to use for emoncms, your credentials and
what data to upload.

**Configure Emoncms**

**Node**
    Grouping that you want to assign to all data upload 
    from this CarbixEnergyMonitor to distinguish it from data uploaded
    from any other devices that you may have. 
    It is somewhat arbitrary and defaults to the name of 
    your CarbixEnergyMonitor device.

**post interval**
    Number of seconds that each data point will represent. 
    The tradeoff is between higher resolution (small interval) 
    and minimizing the storage requirement of the data over 
    time (larger interval). CarbixEnergyMonitor accepts any value
    from 5 seconds to 3600 seconds (1 hour), in 5 second increments. 
    Because of the way Emoncms reports, it's best to use a number 
    that is an even factor or multiple of 
    one minute: 5, 10, 15, 20, 30, 60, 120, etc.

**bulk send**
    Number of interval postings to aggregate into a single 
    posting request. Specifying 1 will send a data packet 
    to Emoncms at each interval. 
    If your interval is 5 or 10, it will send a packet 
    every 5 or 10 seconds. That's fairly inefficient and 
    can be problematic when there are internet connectivity 
    issues. By specifying a larger bulk send, CarbixEnergyMonitor will
    aggregate the posting data for that many intervals and 
    send the data in one packet. 
    For instance if your interval is 10 seconds, 
    specifying bulk send = 3 will cause data to be sent 
    every 30 seconds. Large bulk send values will cause any 
    real-time dashboards in Emoncms to update less frequently, 
    so you should strike a balance. CarbixEnergyMonitor keeps all of the
    data in local storage, so there is no risk of losing data 
    by using this feature. Should there be any failure to deliver, 
    CarbixEnergyMonitor will pick up with the last successful
    posting when the problem resolves itself.

**upload history from**
    When starting a new Emoncms node, you can specify a date 
    from which to upload historical data. 
    To the extent that the data is available in the local datalog, 
    CarbixEnergyMonitor will bulk upload the historical data to Emoncms.
    The bulk upload can take anywhere from several minutes 
    to a day or more depending on the time-frame and the upload speed. 
    Regardless, the historical upload is done in the background 
    and will not significantly affect normal operation.

**server URL** 
    URL of the Emoncms server. This field defaults to the Emoncms.org
    server. The software is open, 
    so you may maintain your own server (software on GitHub) 
    or you may get one of the OpenEnergyMonitor.org products 
    that run a version of the software on a raspberry-pi. 
    When using a local instance of Emoncms, 
    you can use the IP format with optional port number. 
    An example might be http://192.168.0.112:80/emoncms.

    If you have setup a HTTPSproxy server, you can use the HTTPS://
    method here for secure uploads.  There is also a 

**api key**
    A 32 character hexadecimal key to authorize posting to an account. 
    Once you establish your account, 
    locate the read-write api key and copy/paste into this field.

**Emoncms userid**
    By specifying this optional value, you instruct CarbixEnergyMonitor to use
    a secure encrypted protocol to send data to Emoncms. 
    There is no downside to doing this, and it is recommended. 
    Your userid is a four or five digit number located 
    in the "My Account" section of the Emoncms.org site.

Now click **Save** and CarbixEnergyMonitor should begin sending data to
your Emoncms account. You can see the status of the 
Emoncms service in the `Status Display <status.html#web-servers>`__

CarbixEnergyMonitor uploads the current voltage or power corresponding
to all of the input channels in each post. 
You can configure Emoncms (follow their instructions on the website) 
to save only what you want to keep in "feeds". 
Setting up and configuring the Emoncms account is 
documented on the Emoncms.org site.

Customizing Input data
----------------------

You can customize the data that is sent to Emoncms 
using the Emoncms Inputs list at the bottom of the 
configuration screen. This list is very similar to the 
Configure Outputs section, except rather than calculate 
named values that can be viewed in the status screen 
or displayed in the graph application, 
you specify how to calculate the individual inputs 
to Emoncms using the same calculator interface.

Initially, these fields correspond to each of the CarbixEnergyMonitor inputs.
By editing this list, you can change the values that are sent, 
delete specific values, or add additional computed values to be sent.

One distinctive feature of this list vs the outputs list is that the 
names must be numeric values between 1 and 99. 
The name of an entry corresponds to the Emoncms input "key" value. 
When editing the various fields, 
if you add a new entry with the same number as an existing entry, 
or change an entry to the same number as an existing entry, 
it will replace the existing entry. Each time you save an entry, 
the list will be reordered.









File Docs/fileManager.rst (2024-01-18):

=======================
File Manager and Editor
=======================

CarbixEnergyMonitor file systems
---------------------

CarbixEnergyMonitor has two file systems.
The primary file system is maintained on the internal SDcard 
and is formatted as FAT32. Typical SDcard size is 8Gb. 
All of the web server files as well as the 
data and message logs are maintained on the SDcard.

The ESP8266 also has an onboard file system called the 
SPI Flash File System or SPIFFS that is much smaller at 1Mb. 
CarbixEnergyMonitor uses that area for limited device specific information.
This file system uses a flat directory structure, however 
CarbixEnergyMonitor presents it as hierarchical through the file manager.

File Manager
------------

The integrated web server can be used to access and manage 
the files on both the SDcard and in the SPIFFS file system. 
The web server is based on the generic ESPWebserver developed 
by the folks at the ESP8266/Arduino project. 
The file manager application is the unmodified application 
that they distribute. The major functions are:

*   Display file system
*   Delete files
*   Upload files to the CarbixEnergyMonitor
*   Download files from the CarbixEnergyMonitor
*   Edit files

The File Manager is accessed from the dropdown buttons in the 
Tools main menu.

File Manager

The left column is the file list. 
Directories can be expanded by clicking the + sign 
as in the typical paradigm. Action can be taken on individual 
files by right clicking and selecting from the options:

*   Edit
*   Download
*   Delete - Proceed cautiously. 
    There is no confirmation popup. Delete is delete now!

Downloading Files
-----------------

To download a file, right-click it in the file manager as above
and select the Download option. Exactly how it is handled and
where the file is downloaded is a function of your operating
system and browser, but it will follow the normal protocol.

Uploading Files
---------------

Files can be uploaded to the CarbixEnergyMonitor by clicking the
Browse button at the top and selecting a file in the manner 
provided by your browser. Once selected, click Upload to transfer 
the file to the CarbixEnergyMonitor file system. You can edit the
pathname before uploading. 
Additional buttons are provided to create a new directory or file.

SPIFFS
------

The SPIFFS is presented as the directory esp_spiffs. 
Expanding that directory will reveal the contents of 
the SPIFFS with a pseudo hierarchical directory structure. 
Files can be accessed in the same way as on the SDcard.

ACE Editor
----------

One of the most powerful features of this app is the editor. 
It's a version of the open `Ace Editor <https://ace.c9.io/>`__ 
and is very fast and capable. 
It's not particularly useful on mobile devices, 
but does very well on a keyboard equipped browser. 
You will need to learn the keyboard shortcuts, 
but even with just a few of the usual suspects, you can be very 
productive (ctrl-S save, ctrl-Z undo, ctrl-F find, etc.)

The CarbixEnergyMonitor configuration app was developed exclusively
using this editor and an CarbixEnergyMonitor.
In fact, that's the file that appears in the editor 
window when you start the file manager app.

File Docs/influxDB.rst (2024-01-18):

========
influxDB
========

influxDB is a fast open-source time-series database package. 
It can run on a variety of platforms and is also available 
as a managed, fully hosted service, from several vendors. 
As part of their "TICK" stack, InfluxData provides tools to 
facilitate collecting data from a variety of sources, 
as well as tools for infrastructure monitoring, 
alert management, data visualization, and database management. 
The popular grafana visualization tools also work well with influxDB.

CarbixEnergyMonitor fully supports the influxDB HTTP API for uploading data
to influxDB at a specific interval of 5 seconds to one hour. 
Like other similar CarbixEnergyMonitor services, continuity of updates is
maintained despite outages that may interrupt the communications.

This tutorial assumes you have established your own instance of influxDB 
or subscribed to a hosted service. It does not attempt to explain 
how to install or use influx or any of the related visualization tools. 
There's a whole universe of enthusiastic users at the influxData forum,
where you can get help with anything and everything.

influxDB versions 1.x and 2.x
-----------------------------

With the introduction of  InfluxDB 2.0
the basic measurement scheme remains the same, but there are significant changes:

- Authentication is changed from the basic userID/password of 1.x to 
  use of an 88 character base64 token.
- Where version 1.x organizes into a `database`, version 2
  introduces the concept of `buckets`.
- The native query in version 2 uses a new `flux` language as
  opposed to the `influxQuery` language in version 1.x.

There are various compatibility options available for transition fromversion 1.x
to version 2, depending on the implementation (cloud or OSS), but CarbixEnergyMonitor
now supports both versions natively.

The two are similar enough that they will be covered together here with 
breakouts where needed to address the differences.

Configure influxDB uploader
---------------------------

To configure the influxDB upload service in CarbixEnergyMonitor,
Hover over |Setup| and click 
|uploadersButton| from the dropdown menu.

**Setup Menu**

Choose the appropriate version of influxDB...

**Select influxDB**

Depending on the version that you selected, you will get one of two
similar setup menus.

**Version 1 Setup**

**Version 2 Setup**

**post interval**
    Number of seconds that each data point will represent. 
    The trade-off is between higher resolution (small interval) and 
    minimizing the storage requirement of the data over time (larger interval). 
    CarbixEnergyMonitor accepts any value from 5 seconds to 3600 seconds (1 hour),
    in 5 second increments. Although not a strict requirement, 
    it's best to use a number that is an even factor or 
    multiple of one minute: 5, 10, 15, 20, 30, 60, 120, etc.

**bulk send**
    Number of interval postings to aggregate into a single HTTP request. 
    Specifying 1 will send a data packet to influxDB at each interval. 
    If your interval is 5 or 10, it will send a packet every 5 or 10 seconds. 
    That's fairly inefficient and can be problematic when there are internet 
    connectivity issues. By specifying a larger bulk send, 
    CarbixEnergyMonitor will aggregate the posting data for the specified number
    of intervals and send the data in one packet. 
    For instance if your interval is 10 seconds, 
    specifying bulk send = 6 will cause data to be sent every 60 seconds. 
    Large bulk send values will cause any real-time dashboards to update 
    less frequently, so you should strike a balance. 
    CarbixEnergyMonitor keeps all of the data in the SD data log,
    so there is no risk of losing data by using this feature. 
    Should there be any failure to deliver, 
    CarbixEnergyMonitor will pick up with the last successful posting when the problem is resolved.

**server URL**
    URL of the influxDB server. If the URL begins with HTTPS:// you must have
    specified a HTTPSproxy_ server.
    The url may contain a domain name or an IP address. 
    The *:port number* is optional and defaults to the influxDB port 8086 for version 1.

    .. _HTTPSproxy HTTPSproxy.rst
    
**upload history from**
    Specify the starting date that CarbixEnergyMonitor will use to upload history
    to a new set of measurements. When the influxDBService starts, 
    a query is made to determine the date/time of the last data written, 
    qualified by the first tag-set. Data upload is initiated as follows:

    ============================ ============================================== ========================
    Condition                    begin date specified                           begin date not specified
    ============================ ============================================== ========================
    new measurement set          begin date 00:00                               current date/time
    existing measurement set     greater of last entry date/time or begin date  last entry date/time
    ============================ ============================================== ========================

**measurement**
    Name that you assign to the measurements that CarbixEnergyMonitor will be posting.
    The specification can be a constant string, or can include variables 
    as explained below under variables. Note that if not specified, 
    the variable $name will be used.

Unique Version 1 Parameters
---------------------------

**database**
    Name of the influxDB database that you 
    have created to be the repository for the CarbixEnergyMonitor data.

**retention policy**
    Optional name of the influxDB retention policy that you want to associate 
    with the measurements that are written to influxDB.
    If not specified influx will use the default policy. 
    If you specify a retention policy, it must be defined to influxDB before data can be written.

**username/password** 
    Optional security credentials. If specified, CarbixEnergyMonitor will
    use standard authorization headers with these credentials.

Unique Version 2 Parameters
---------------------------

**bucket**
    The name of the influxDB `bucket` to contain the measurements.
    Roughly the equivalent of the `database` in v1.

**organization ID**
    The 16 hex-digit organization identifier specific to the server instance.
    Organization Id is found from the InfluxDB Web GUI by clicking your user
    icon on the left navigation bar, then `About` and copy the 16 hex-digit value.

**Authorization token**
    Authorization token produced by influx. (Data->Tokens->Generate Token-> Read/Write Token for CarbixEnergyMonitor bucket)
    This is an 88 character base64 string that should be
    copied and pasted to avoid transcription errors.  The token is the shared secret that
    authorizes access to the bucket.

tag-set
-------

**tag-set** 
    A collection of optional user specified tag-key/tag-value pairs 
    that will be included as part of each measurement. 
    The influx documentation somewhat explains them here. 
    Basically, these tags each produce a table index that can be helpful 
    in increasing the performance of data retrieval. 
    The first tag-set is a special case for CarbixEnergyMonitor, and if specified,
    is used to uniquely identify the measurement subset from this device 
    so that upload can resume seamlessly. If this is not the only device 
    that will be posting to the database, 
    a unique identifier for this device should be included as the 
    first entry in a tag-set. tag-values can be a constant string 
    or can include variables as explained below under variables

    edit an existing tag by clicking on it's associated edit button,
    or add a new one with the add button. add tag-set

**Influx tag-set**

**field-key** 
    Each measurement contains a field key and field value. 
    The field value is always the value specified in the "calculator" function. 
    The field key to be used is specified here. 
    It can be a constant string or can include variables as 
    explained below under variables. If not specified, 
    the default field key in each measurement is the string 'value'.

measurements
------------

**measurements** 
    The set of *measurement*s that will be sent at each interval. 
    The editor uses the "calculator" interface to
    create scripts to generate data using the various CarbixEnergyMonitor inputs.
    Each entry will generate a measurement using the influx line protocol::

    <measurement>[,tag-key1=tag-value1[,tag-key2=tag-value2...]] field-key=field-value time

Note that **measurement**, **tag-value**, and **field-key** are specified 
above and can be fixed strings or can be or contain variables. 
Some examples of the various ways this can be used to create different 
types of measurement specifications are given below.

As each measurement is written the *$name* and *$units* variables are 
assigned the value specified in the individual measurement specification.

The units of the field set defaults to watts. 
While Watts is the typical unit reported, the following additional units are available.

    *   watts
    *   volts
    *   VA
    *   pf
    *   Hz
    *   kW
    *   wH
    *   kWh

Once configured, a new influx service will be created. 
The current state of the service and the date/time of last update 
will be displayed under the influxDB tab in the status display.

influx status bar

The service can be started and stopped using the start/stop button. 
When a running influx service is changed, the service is automatically stopped and restarted.

Variables
---------

Variables provide a way to further customize the way data 
is organized in your influxDB database. This tutorial will not get 
into the implications of different conventions, except to say that future 
generic visualization templates may be based on using the default 
specifications for measurement and field key.

There are three variables defined: 

    *   **$device** - The name assigned to this CarbixEnergyMonitor device
        in the device configuration section. 
    *   **$name** - The name specified for the current measurement 
    *   **$units** - The units specified for the current measurement

When these variables appear as all or part of the string specified 
for measurement field key or a tag value, 
the instance of the variable name is replaced by it's value. 
Evaluation proceeds left to right in a string.

So as an example, when generating a measurement configured as:

**Influx Solar Output**

with a device name of CarbixHome and the current value of the input
solar of 2944.6, 
the following different measurements could be generated:
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

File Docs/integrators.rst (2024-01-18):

============
Integrators
============

What are integrators?
----------------------

The datalog provides high speed access to all monotonic data derived 
directly from the datalog or indirectly with output Scripts.  That is to say, if
the total value only increases, or only decreases, everything works just fine.

The exception is where a CT is configured with "allow negative values" as with 
a mains CT where solar or other alternative energy sources can send excess
energy to the grid.  In those cases, the total energy represented is the net 
energy, and is not a monotonically increasing value. Additionally, Scripts that do 
not result in monotonically increasing values may not produce the intended result.

The individual five-second data in the datalog is the signed net energy
imported (+) or exported (-) during each interval. When that data is viewed in a broader context 
of hours, the net does not provide accurate individual import and export values.
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

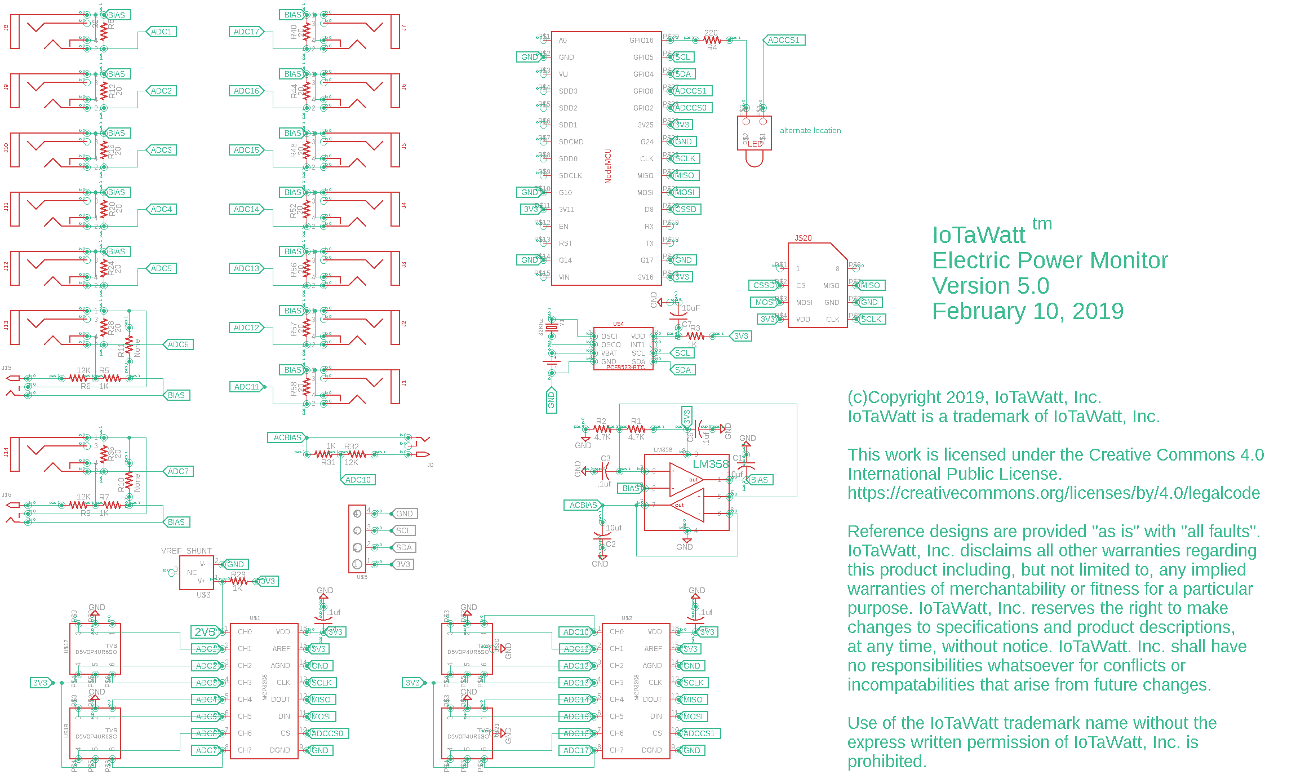
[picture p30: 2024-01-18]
Hardware/V5_schematic.png

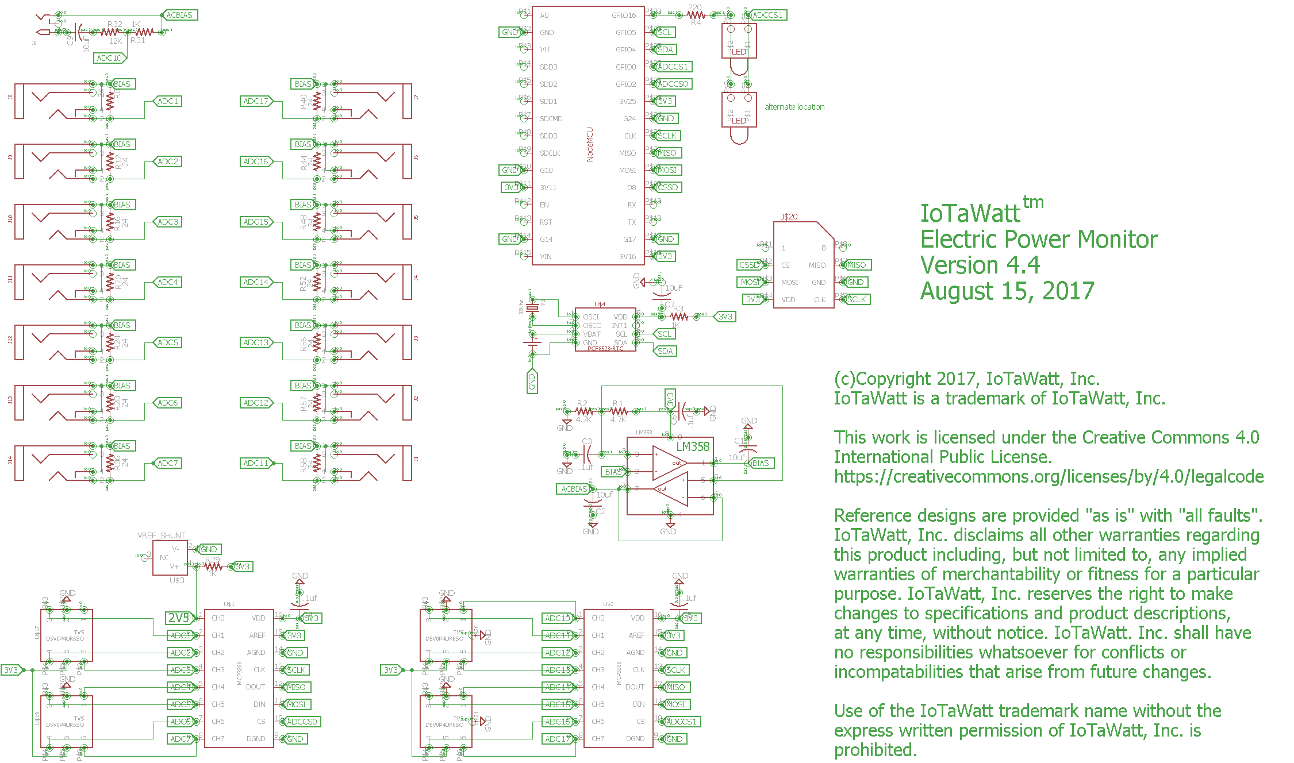
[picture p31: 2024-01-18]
Hardware/IoTaWattSCH.png

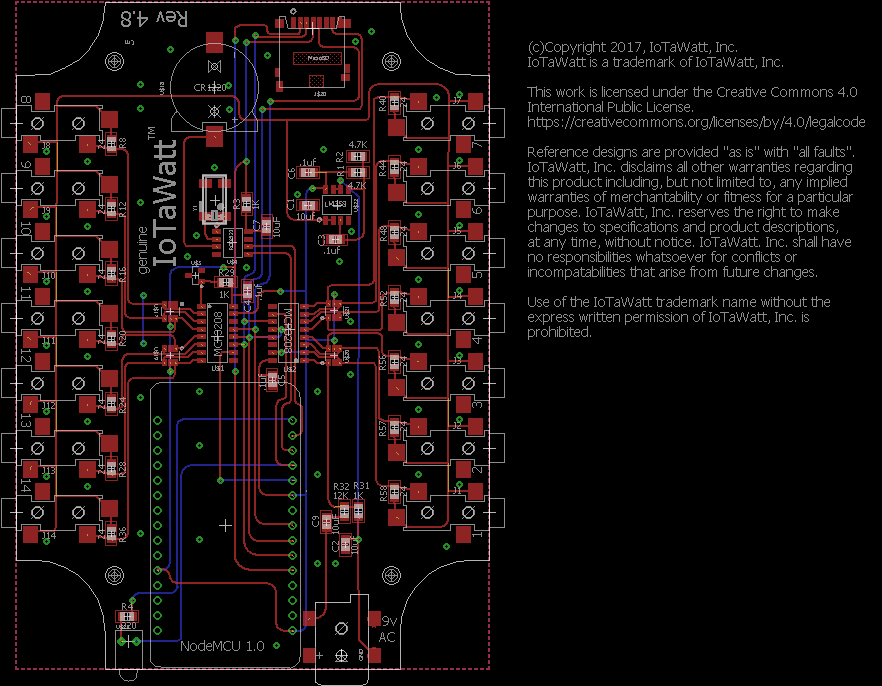
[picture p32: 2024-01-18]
Hardware/IoTaWattPCB.png

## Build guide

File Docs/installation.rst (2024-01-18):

Installation
============

Software vs. Hardware
---------------------

Strictly speaking, CarbixEnergyMonitor began as a software project
with no specific hardware platform in mind.
That objective was soon supplanted by an open hardware 
design based on the ESP8266. Typical CarbixEnergyMonitor installations
use a commercially manufactured unit that is certified to 
UL and CE safety standards and complies with FCC requirements.

The CarbixEnergyMonitor firmware is factory installed and
can be automatically and securely updated over WiFi.
This section of the documentation deals with the physical 
installation of the commercial CarbixEnergyMonitor unit with factory
installed firmware.

Components
----------

CarbixEnergyMonitor has 15 input channels.
One is reserved for monitoring voltage, 
and the remaining 14 can be used to monitor power *or* voltage.
The minimum requirements for operation are:

    * CarbixEnergyMonitor
    * USB power supply
    * AC voltage reference transformer
    * Current Transformer (one or more)

Voltage and Frequency
---------------------

CarbixEnergyMonitor can work with all common line voltages at 50Hz/60Hz.
Additionally, it can use multiple voltage references for 
polyphase measurement.
The most common environments are 120/240V 60Hz and 230V 50Hz.
The USB power supply and AC transformer must be appropriate for the power system.

Connections
-----------

Setup is simple:

 #. Connect the USB power supply to the ``5V DC USB``
 #. Connect the AC transformer to the ``9V AC REF``
 #. Plug the power supply and AC transformer into a wall socket

That's it.

Next step: `connecting to WiFi <connectWiFi.html>`__

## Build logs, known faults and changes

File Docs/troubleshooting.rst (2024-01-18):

===============
Troubleshooting
===============

Led Indicator
-------------

The CarbixEnergyMonitor has a bi-color external LED indicator that is usefull in
determining the current state and for explicitely indicating 
serious problems. Whenever there is a question about whether 
something may be wrong, it is important to look at the LED indicator. 
The LED can blink RED (R) or GREEN (G). 
When indicating a device state, it will repeat a sequence of 
colored blinks.

Dull Green Glow
---------------

This typically means that the device is connected and working properly.

Dull Red Glow
-------------

This indicates that the device is working properly, 
but either there is no WiFi connection or the real time clock 
is not initialized and the time cannot be established from 
time-servers on the internet via WiFi. 
As long as the real time clock is initialized, 
the CarbixEnergyMonitor can run indefinitely without WiFi.
If you are logging to Emoncms or another server, 
that will be suspended, but CarbixEnergyMonitor will recognize
when the WiFi connection is restored, 
change the led to dull green, 
and send all of the data that it was unable to send during the outage.

To determine if CarbixEnergyMonitor is connected to the WiFi network,
try to run the CarbixEnergyMonitor app from a browser on a device that
is connected to the same WiFi network. 
If it works, the problem was probably the real time clock. 

If the app doesn't start, there is a problem with the WiFi connection. 
To be sure, restart the CarbixEnergyMonitor by disconnecting the 5VDC power momentarily
and then observe the led during startup. 
Follow the troubleshooting guide for led indications during startup.

Not Illuminated
---------------

Under virtually all circumstances, the led should be illuminated. 
If not, the most probable cause is that there is no 5VDC supply. 
The power supply may be faulty or the USB plug may not be inserted all the way.
Check these things first. Try unplugging the 5VDC USB supply and reconnecting. 
Try a different 5VDC supply if available. If all else fails, a more serious 
problem with the device must be considered. 
Consult the supplier or someone who can troubleshoot electronic the hardware.

Continuous Red-Green-Red-Green.....
-----------------------------------

Downloading new firmware release. 
Updates are published from time to time and most CarbixEnergyMonitor subscribe
to an auto-update class for which the current release may change. 
When a new release becomes available, 
the device initiates a download of a large file that contains 
all of the elements of the new release. 
The download usually takes about 5-6 seconds, but can take longer. 
While the download is in progress, the CarbixEnergyMonitor does nothing else
and will blink the led RED-GREEN continuously. 
At the completion of the download, 
the release will be installed and your CarbixEnergyMonitor will restart.
The entire process should never take more than a minute.

Led Sequences
-------------

red-green-green
^^^^^^^^^^^^^^^

CarbixEnergyMonitor is having trouble connecting to the WiFi network.
If this is a new CarbixEnergyMonitor, or the network has changed,
you will need to specify a new network. 
Otherwise, wait several minutes and the LED pattern 
should change to a new code. Follow the advice for that code.

red-green-red
^^^^^^^^^^^^^

A corrupted datalog (current or history) has been discovered. 
The file is being scanned from beginning top end and a diagnostic 
file will be created. This can take an hour or more for large logs. 
Allow to run to completion, after which the damaged log will be 
deleted and a new log created.

red-red-green
^^^^^^^^^^^^^

The configured WiFi network is unavailable and the real-time-clock 
is not running. CarbixEnergyMonitor can run without WiFi,
but it cannot accumulate log data if it doesn't know what time it is, 
and it sets the real-time-clock from the internet. 
Determine the problem with your WiFi network or connect to a new network.

green-red-red
^^^^^^^^^^^^^

CarbixEnergyMonitor is having trouble accessing the SDcard inside the device.
This typically happens during a restart of the device. 
You will need to power off the device and open it up by 
removing the four screws located under the rubber feet. 
Check that the SDcard is firmly seated in the socket and retry.

If problem persists, your card may have failed. 
You can try to insert the card into a computer that accepts SD 
cards to see if it can be read. If so, the problem is probably 
the CarbixEnergyMonitor SD card socket and the device will need to be replaced.
The good news is that the card should work in a replacement device 
and pick up where you left off with all historical data intact.

If your card cannot be read by another device, it is probably 
the card itself. Unfortunately, these things do fail from time-to-time. 
To be sure, insert any other available SDcard and try to restart. 
If the error indication changes to something else, it is probably 
a failure of the SDcard. Sadly, you will need to obtain a new 
one and initialize it with the files that are in the SD directory 
of the GitHub project. All historical data is lost and you will 
need to reconfigure the device as if were new.

red-red-red
^^^^^^^^^^^

This is a catch-all panic code, where the firmware has detected a 
situation that should not happen, or is impossible to deal with. 
Possibly there will be some diagnostic clues in the message log, 
or it may require connecting a serial terminal to the USB port 
to obtain further diagnostics. Problems in this category are beyond 
the scope of this document.

green-red-red-red
^^^^^^^^^^^^^^^^^

The config.txt file was not found on the SDcard.  Possibly
the SDcard has been damaged, or the file was inadvertently
deleted.  The card must be removed, examined in another 
computer, and a new config.txt file provided.

green-red-red-green
^^^^^^^^^^^^^^^^^^^

The config.txt file format is invalid (not valid Json)
and could not be used.  This could be the result of
editing the file improperly, or an error in saving the
configuration.  It may be possible to repair the file 
by mounting the SDcard in another computer and using
a Json linter to find the errors.  Otherwise, it may 
be necessary to replace the config.txt file.

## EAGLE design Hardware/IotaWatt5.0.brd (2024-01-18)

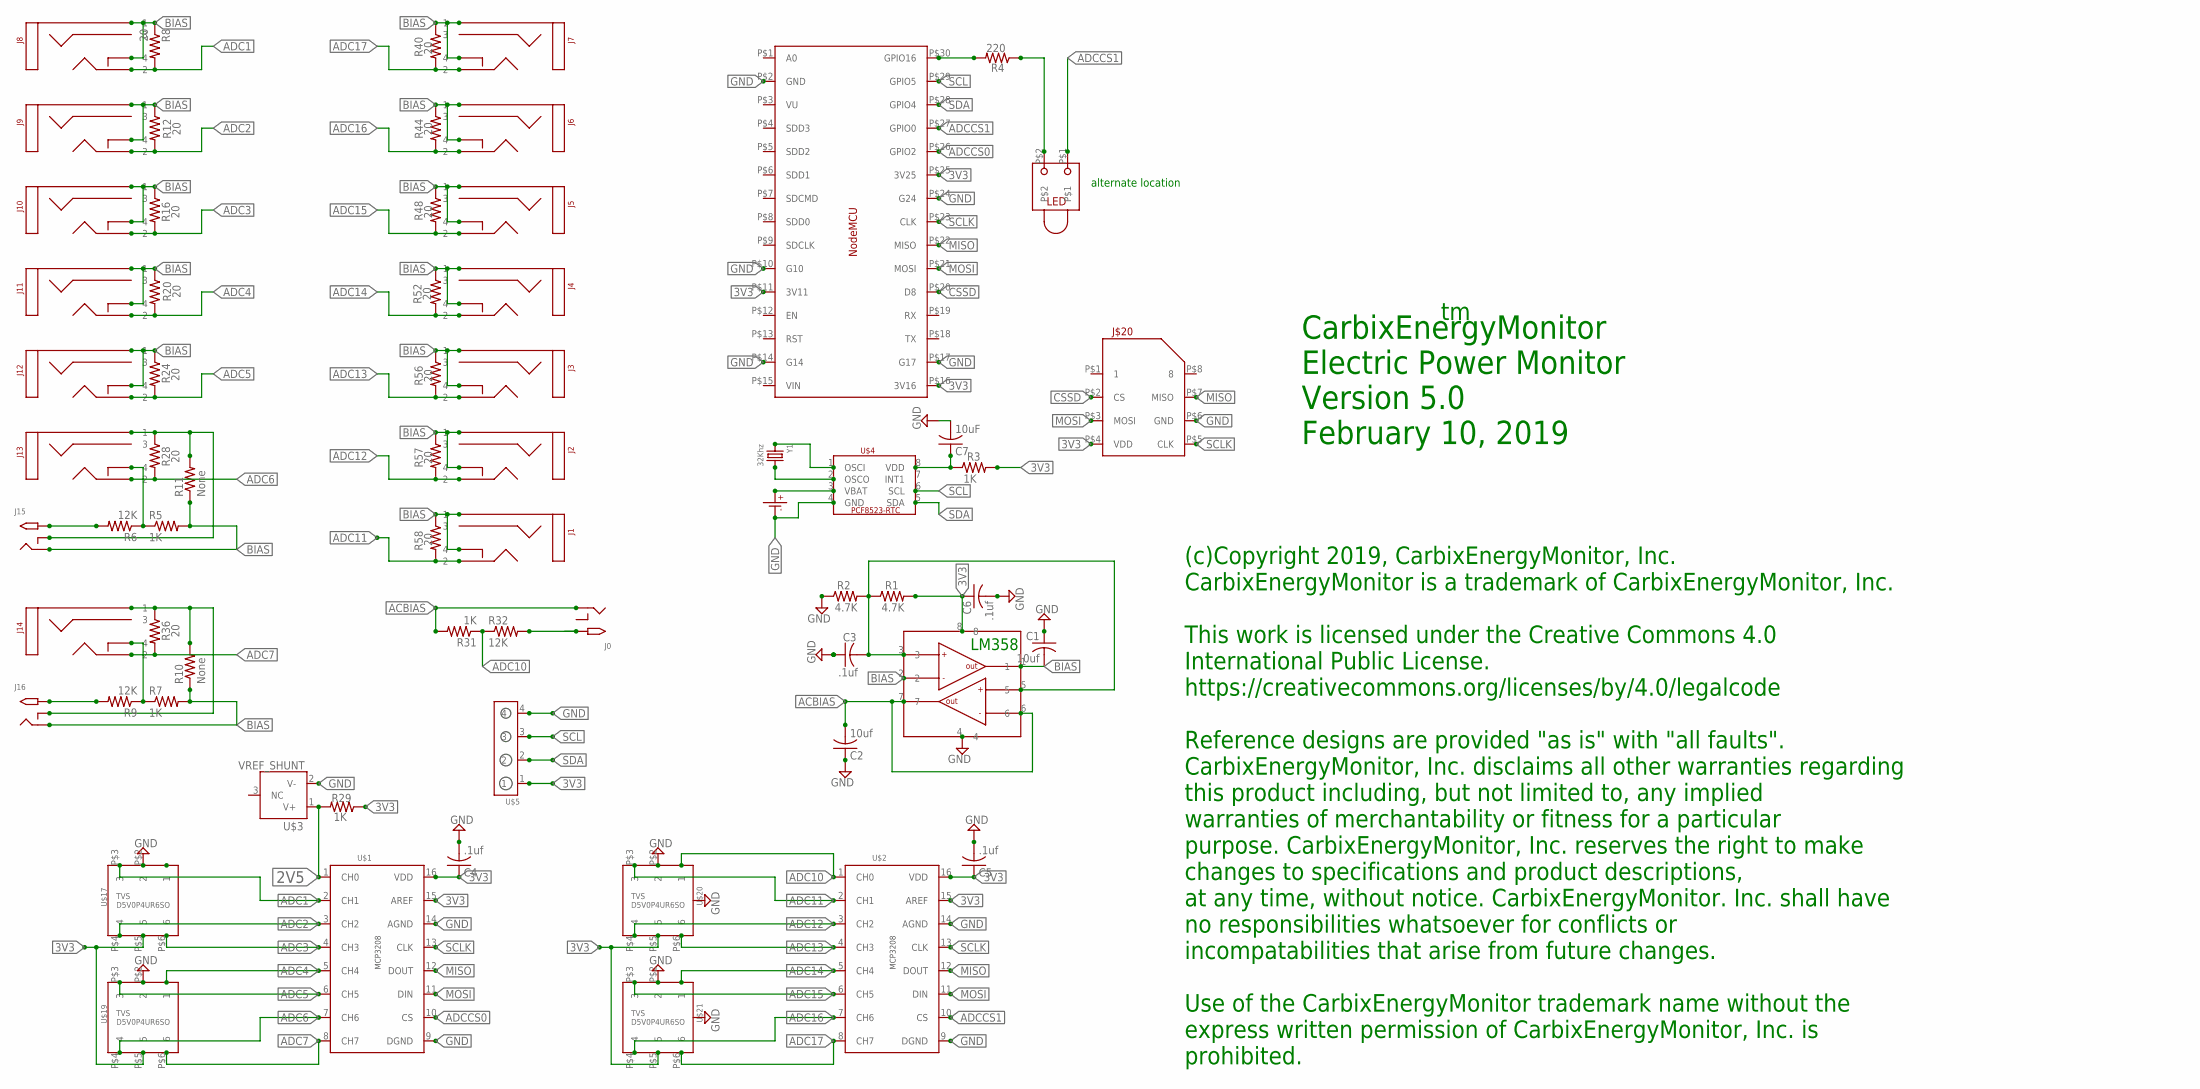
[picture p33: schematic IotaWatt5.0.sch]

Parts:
C1, C2: 10uf; C0805
C3, C4, C5, C6: .1uf; C0805
C7: 10uF; C0805
J0, J15, J16: 2.1MMJACKSMT; DCJACK_2MM_SMT
J1, J2, J3, J4, J5, J6, J7, J8, J9, J10, J11, J12, J13, J14: STEREO_SMD; STEREO_SMT
J$20: MICROSD_PUSH/PULL; MICROSD
R1, R2: 4.7K; R0805
R3, R5, R7, R29, R31: 1K; R0805
R4: 220; R0805
R6, R9, R32: 12K; R0805
R8, R12, R16, R20, R24, R28, R36, R40, R44, R48, R52, R56, R57, R58: 20; R0805
R10, R11: None; R0805
U$1, U$2: MCP3208; SOIC_16
U$3: VREF_SHUNT; SOT23_3
U$4: PCF8523_RTC; SOIC_8
U$5: HEADER_1X4
U$16: NODEMCU
U$17, U$19, U$20, U$21: TVS_4CHAN_ARRAYSC-74; SC-74
U$18: CR1220SMD
U$22: LM358_DUAL_OP-AMP; SOIC_8
U$23: LED_RT_TRH; LED_TH_RT
Y1: 32Khz; CRYSTAL_8X3.8

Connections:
2V5: R29.2, U$1.1 (CH0), U$3.1 (V+)
3V3: C4.1, C5.1, C6.1, J$20.P$4 (VDD), R1.2, R3.2, R29.1, U$1.15 (AREF), U$1.16 (VDD), U$2.15 (AREF), U$2.16 (VDD), U$5.1, U$16.P$11 (3V11), U$16.P$16 (3V16), U$16.P$25 (3V25), U$17.P$5 (5), U$19.P$5 (5), U$20.P$5 (5), U$21.P$5 (5), U$22.8
ACBIAS: C2.2, J0.GND (RING), R31.2, U$22.6, U$22.7
ADC1: J8.P$2 (2), R8.2, U$1.2 (CH1), U$17.P$3 (3)
ADC2: J9.P$2 (2), R12.2, U$1.3 (CH2), U$17.P$4 (4)
ADC3: J10.P$2 (2), R16.2, U$1.4 (CH3), U$17.P$6 (6)
ADC4: J11.P$2 (2), R20.2, U$1.5 (CH4), U$19.P$1 (1)
ADC5: J12.P$2 (2), R24.2, U$1.6 (CH5), U$19.P$3 (3)
ADC6: J13.P$2 (2), R28.2, U$1.7 (CH6), U$19.P$4 (4)
ADC7: J14.P$2 (2), R36.2, U$1.8 (CH7), U$19.P$6 (6)
ADC10: R31.1, R32.1, U$2.1 (CH0), U$20.P$1 (1)
ADC11: J1.P$2 (2), R58.2, U$2.2 (CH1), U$20.P$3 (3)
ADC12: J2.P$2 (2), R57.2, U$2.3 (CH2), U$20.P$4 (4)
ADC13: J3.P$2 (2), R56.2, U$2.4 (CH3), U$20.P$6 (6)
ADC14: J4.P$2 (2), R52.2, U$2.5 (CH4), U$21.P$1 (1)
ADC15: J5.P$2 (2), R48.2, U$2.6 (CH5), U$21.P$3 (3)
ADC16: J6.P$2 (2), R44.2, U$2.7 (CH6), U$21.P$4 (4)
ADC17: J7.P$2 (2), R40.2, U$2.8 (CH7), U$21.P$6 (6)
ADCCS0: U$1.10 (CS), U$16.P$26 (GPIO2)
ADCCS1: U$2.10 (CS), U$16.P$27 (GPIO0), U$23.P$1
BIAS: C1.2, J1.P$1 (1), J1.P$4 (4), J2.P$1 (1), J2.P$4 (4), J3.P$1 (1), J3.P$4 (4), J4.P$1 (1), J4.P$4 (4), J5.P$1 (1), J5.P$4 (4), J6.P$1 (1), J6.P$4 (4), J7.P$1 (1), J7.P$4 (4), J8.P$1 (1), J8.P$4 (4), J9.P$1 (1), J9.P$4 (4), J10.P$1 (1), J10.P$4 (4), J11.P$1 (1), J11.P$4 (4), J12.P$1 (1), J12.P$4 (4), J15.GND (RING), J16.GND (RING), R5.2, R7.2, R8.1, R10.1, R11.1, R12.1, R16.1, R20.1, R24.1, R40.1, R44.1, R48.1, R52.1, R56.1, R57.1, R58.1, U$22.1, U$22.2
CSSD: J$20.P$2 (CS), U$16.P$20 (D8)
GND: C1.1, C2.1, C3.1, C4.2, C5.2, C6.2, C7.2, J$20.P$6 (GND), R2.1, U$1.9 (DGND), U$1.14 (AGND), U$2.9 (DGND), U$2.14 (AGND), U$3.2 (V-), U$4.4 (GND), U$5.4, U$16.P$2 (GND), U$16.P$10 (G10), U$16.P$14 (G14), U$16.P$17 (G17), U$16.P$24 (G24), U$17.P$2 (2), U$18.P- (P$-), U$19.P$2 (2), U$20.P$2 (2), U$21.P$2 (2), U$22.4
MISO: J$20.P$7 (MISO), U$1.12 (DOUT), U$2.12 (DOUT), U$16.P$22 (MISO)
MOSI: J$20.P$3 (MOSI), U$1.11 (DIN), U$2.11 (DIN), U$16.P$21 (MOSI)
unnamed: C7.1, R3.1, U$4.8 (VDD)
unnamed: J15.PWR2 (TIP), R6.2
unnamed: J16.PWR2 (TIP), R9.2
unnamed: J14.P$1 (1), J16.GNDBREAK (RING_SW), R10.2, R36.1
unnamed: J13.P$1 (1), J15.GNDBREAK (RING_SW), R11.2, R28.1
unnamed: J14.P$4 (4), R7.1, R9.1
unnamed: R4.1, U$23.P$2
unnamed: J13.P$4 (4), R5.1, R6.1
unnamed: R4.2, U$16.P$30 (GPIO16)
unnamed: J0.PWR2 (TIP), R32.2
unnamed: U$4.3 (VBAT), U$18.P+ (P$+)
unnamed: U$4.2 (OSCO), Y1.P$4 (2)
unnamed: U$4.1 (OSCI), Y1.P$1 (1)
SCL: U$4.6 (SCL), U$5.3, U$16.P$29 (GPIO5)
SCLK: J$20.P$5 (CLK), U$1.13 (CLK), U$2.13 (CLK), U$16.P$23 (CLK)
SDA: U$4.5 (SDA), U$5.2, U$16.P$28 (GPIO4)
VREF: C3.2, R1.1, R2.2, U$22.3, U$22.5

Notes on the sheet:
CarbixEnergyMonitor Electric Power Monitor Version 5.0 February 10, 2019
alternate location
LM358
(c)Copyright 2019, CarbixEnergyMonitor, Inc. CarbixEnergyMonitor is a trademark of CarbixEnergyMonitor, Inc. This work is licensed under the Creative Commons 4.0 International Public License. https://creativecommons.org/licenses/by/4.0/legalcode Reference designs are provided "as is" with "all faul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

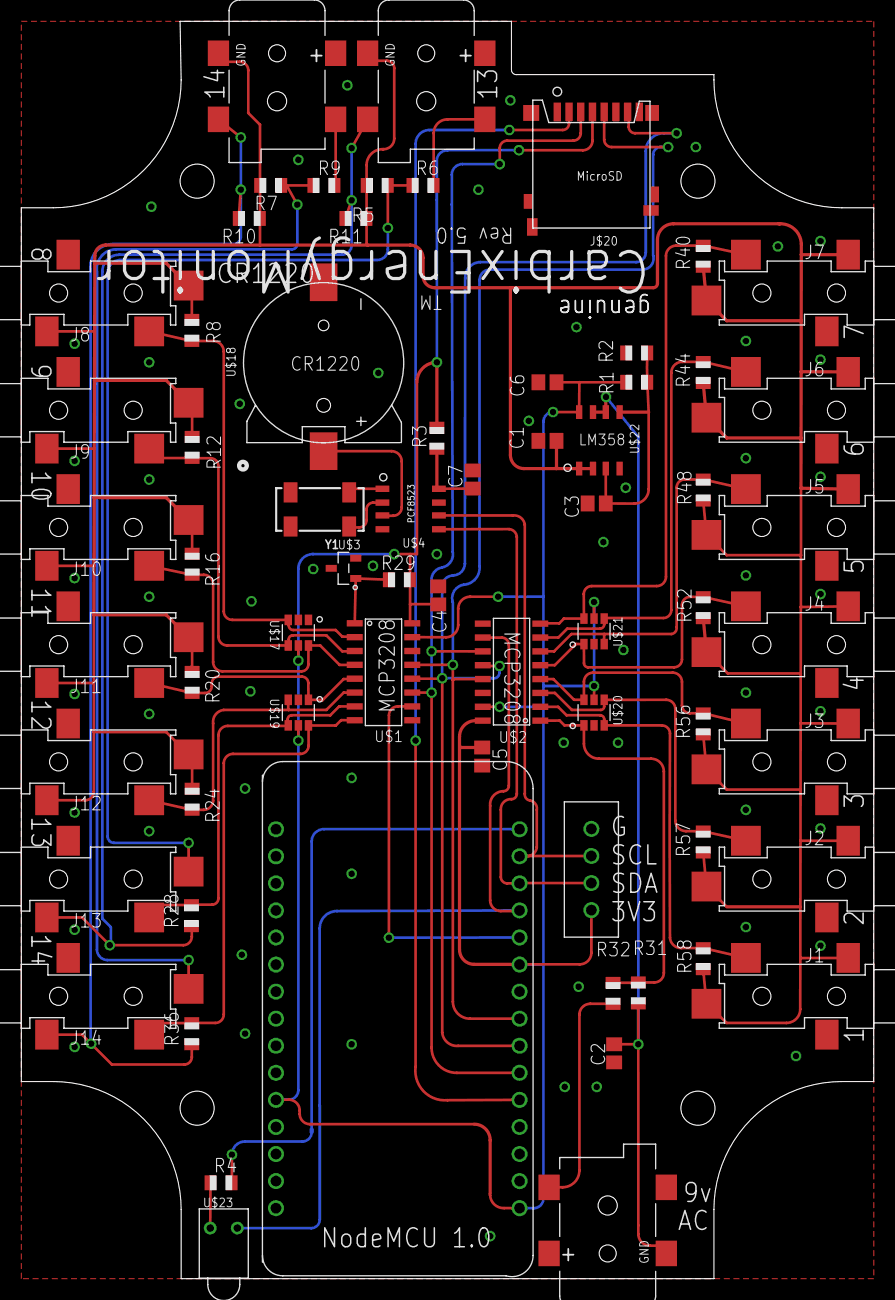
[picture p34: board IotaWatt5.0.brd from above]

Board: 2 copper layers, 80.0 x 118.0 mm, 66 parts (0 on the bottom side), 42 nets.

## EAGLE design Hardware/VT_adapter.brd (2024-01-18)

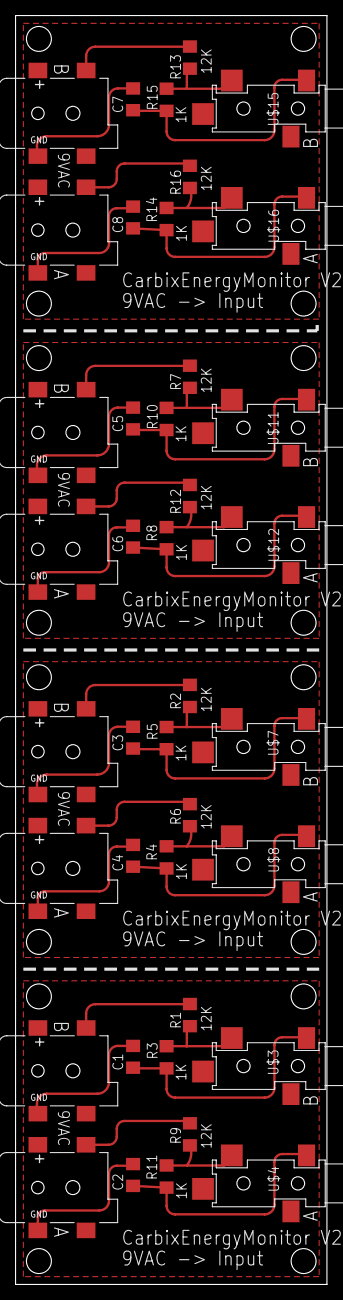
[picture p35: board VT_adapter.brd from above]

Board: 2 copper layers, 40.0 x 163.0 mm, 40 parts (0 on the bottom side), 32 nets.

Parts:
C1, C2, C3, C4, C5, C6, C7, C8: 10uf; C1206
R1, R2, R6, R7, R9, R12, R13, R16: 12K; R1206
R3, R4, R5, R8, R10, R11, R14, R15: 1K; R1206
U$1, U$2, U$5, U$6, U$9, U$10, U$13, U$14: 2.1MMJACKSMT; DCJACK_2MM_SMT
U$3, U$4, U$7, U$8, U$11, U$12, U$15, U$16: STEREO_SMD; STEREO_SMT

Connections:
unnamed: C1.2, R3.2, U$3.P$1
unnamed: R1.2, R3.1, U$3.P$2
unnamed: C1.1, U$1.GND
unnamed: C2.1, U$2.GND
unnamed: R4.2, R6.2, U$8.P$2
unnamed: R1.1, U$1.PWR2
unnamed: R9.1, U$2.PWR2
unnamed: C4.2, R4.1, U$8.P$1
unnamed: C3.2, R5.2, U$7.P$1
unnamed: C3.1, U$5.GND
unnamed: R9.2, R11.2, U$4.P$2
unnamed: C2.2, R11.1, U$4.P$1
unnamed: R2.1, U$5.PWR2
unnamed: C4.1, U$6.GND
unnamed: R6.1, U$6.PWR2
unnamed: R2.2, R5.1, U$7.P$2
unnamed: R8.2, R12.2, U$12.P$2
unnamed: C6.2, R8.1, U$12.P$1
unnamed: C5.2, R10.2, U$11.P$1
unnamed: C5.1, U$9.GND
unnamed: R7.1, U$9.PWR2
unnamed: C6.1, U$10.GND
unnamed: R12.1, U$10.PWR2
unnamed: R7.2, R10.1, U$11.P$2
unnamed: R14.2, R16.2, U$16.P$2
unnamed: C8.2, R14.1, U$16.P$1
unnamed: C7.2, R15.2, U$15.P$1
unnamed: C7.1, U$13.GND
unnamed: R13.1, U$13.PWR2
unnamed: C8.1, U$14.GND
unnamed: R16.1, U$14.PWR2
unnamed: R13.2, R15.1, U$15.P$2

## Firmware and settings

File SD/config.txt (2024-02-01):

{
	"format": 2,
	"timezone": 0,
	"update": "MINOR",
	"device": {
		"name": "CarbixEnergyMonitor",
		"version": 3,
		"channels": "15",
		"burden": [
			0,
			20,
			20,
			20,
			20,
			20,
			20,
			20,
			20,
			20,
			20,
			20,
			20,
			20,
			20
		]
	},
	"inputs": [
		{
			"channel": 0,
			"name": "Input_0",
			"type": "VT",
			"model": "TDC DA-10-09-E6",
			"cal": 10.79,
			"phase": 0.07
		},
		null,
		null,
		null,
		null,
		null,
		null,
		null,
		null,
		null,
		null,
		null,
		null,
		null,
		null
	],
	"outputs": []
}

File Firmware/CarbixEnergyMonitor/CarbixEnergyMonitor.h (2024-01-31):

#ifndef CarbixEnergyMonitor_h
#define CarbixEnergyMonitor_h

/*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
    You should have received a copy of the GNU General Public License
    along with this program.  If not, see <https://www.gnu.org/licenses/>.   
***********************************************************************************/
#define CARBIX_ENERGY_MONITOR_VERSION "02_08_03"
#define DEVICE_NAME "CarbixEnergyMonitor"

#define PRINT(txt,val) Serial.print(txt); Serial.print(val);      // Quick debug aids
#define PRINTL(txt,val) Serial.print(txt); Serial.println(val);
#define MIN(a,b) ((a<b)?a:b)
#define MAX(a,b) ((a>b)?a:b)
#define RANGE(x,min,max) (x<=min?min:(x>=max?max:x))

#include <Arduino.h>
#include <time.h>
#include <EEPROM.h>
#include <ESP8266WiFi.h>
#include <WiFiManager.h>
#include <WiFiClient.h>
#include <ESP8266WebServer.h>
#include <ESPAsyncTCP.h>
#include <asyncHTTPrequest.h>

#include <SPI.h>
#include <RTC.h>
#include <SD.h>
#include <Wire.h>
#include <ArduinoJson.h>
#include <math.h>
#include <Ticker.h>

#include "CarbixLog.h"
#include "CarbixInputChannel.h"
#include "CarbixScript.h"

#include <Crypto.h>
#include <AES.h>
#include <CBC.h>
#include <SHA256.h>
#include <Ed25519.h>

#include "messageLog.h"
#include "utilities.h"
#include "webServer.h"
#include "updater.h"
#include "samplePower.h"
#include "uploader.h"
#include "integrator.h"
#include "auth.h"
#include "spiffs.h"
#include "timeServices.h"
#include "PVoutput.h"
#include "CSVquery.h"
#include "xbuf.h"
#include "xurl.h"
#include "simSolar.h"

      // Declare global instances of classes

extern WiFiClient WifiClient;
extern WiFiManager wifiManager;
extern ESP8266WebServer server;
extern CarbixLog Current_log;
extern CarbixLog History_log;
extern CarbixLog *Export_log;
extern RTC rtc;
extern Ticker Led_timer;
extern messageLog Message_log;
extern simSolar *simsolar;

#define SECONDS_PER_MINUTE 60
#define SECONDS_PER_HOUR 3600
#define SECONDS_PER_SEVENTY_YEARS 2208988800UL

#define MS_PER_HOUR   3600000UL

      // Declare filename Strings of system files.

#define CARBIX_SYSTEM_DIR       "/carbixenergymonitor/"
#define CARBIX_EXPORT_LOG_PATH  "/carbixenergymonitor/export.log"
#define CARBIX_CURRENT_LOG_PATH "/carbixenergymonitor/carbixlog.log"
#define CARBIX_HISTORY_LOG_PATH "/carbixenergymonitor/histlog.log"
#define CARBIX_MESSAGE_LOG_PATH "/carbixenergymonitor/carbixmsgs.txt"
#define CARBIX_AUTH_PATH        "/carbixenergymonitor/auth.txt"
#define CARBIX_CONFIG_PATH      "/config.txt"
#define CARBIX_CONFIG_NEW_PATH  "/config+1.txt"
#define CARBIX_CONFIG_OLD_PATH  "/config-1.txt"
#define CARBIX_TABLE_PATH       "/tables.txt"
#define CARBIX_NEW_TABLE_PATH   "/table+1.txt"
#define CARBIX_INTEGRATIONS_DIR "/carbixenergymonitor/integrations/"
#define CARBIX_UPDATE_HOST      "carbix.co"
#define CARBIX_VERSIONS_PATH    "/firmware/versions.json"
#define CARBIX_VERSIONS_DIR     "/firmware/bin/"
#define CARBIX_TABLE_DIR        "/download/tables/"

extern char* deviceName;

        // Define the hardware pins


#define pin_CS_ADC0 0                       // Define the hardware SPI chip select pins
#define pin_CS_ADC1 2
#define pin_CS_SDcard 15

#define pin_I2C_SDA 4                       // I2C for rtc.  Wish it were SPI.
#define pin_I2C_SCL 5

#define redLed 16                           // CarbixEnergyMonitor overusage of pins
#define greenLed 0

extern uint8_t ADC_selectPin[2];            // indexable reference for ADC select pins

      // Trace context and work area

union traceUnion {
      uint32_t    traceWord;
      struct {
            uint8_t     seq;
            uint8_t     mod;
            uint8_t     id;
            uint8_t     det;
      };
};

extern traceUnion traceEntry;

      // Structure of EEPROM

struct EEprom {
      char        id[8];                  // Valid EE area identifier "CarbixEnergyMonitor"
      uint8_t     EEversion;              // Version of this EE (higher is superset)
      uint8_t     deviceMajorVersion;     // Major version of PCB as "4" in 4.8
      uint8_t     deviceMinorVersion;     // Minor version of PCB as "8" in 4.8
      uint8_t     mfgBurden;              // Burden resistor value at manufacture
      uint16_t    mfgRefVolts;            // Voltage reference at manufacture in mV
      uint16_t    reserved;               // alignment
      uint32_t    mfgDate;                // Unix time          
      uint32_t    mfgLot;                 // Manufacturing lot
      };

      // Identifiers used to construct id numbers for graph API

#define QUERY_VOLTAGE  1
#define QUERY_POWER  2
#define QUERY_ENERGY 3
#define QUERY_OTHER 4

     // RTC trace trace module values by module. (See trace routines in Loop tab)

#define T_LOOP 1           // Loop
#define T_LOG 2            // dataLog
#define T_Emoncms 3        // Emoncms uploader
#define T_GFD 4            // GetFeedData
#define T_UPDATE 5         // updater
#define T_SETUP 6          // Setup
#define T_influx 7         // influxDB
#define T_SAMP 8           // sampleCycle
#define T_POWER 9          // Sample Power
#define T_WEB 10           // (30)Web server handlers
#define T_CONFIG 11        //  Get Config
#define T_encryptEncode 12 //  base64encode and encryptData in EmonService
#define T_uploadGraph 13 
#define T_history 14
#define T_base64 15        // base 64 encode
#define T_stats 18         // Stat service 
#define T_datalog 19       // datalog service
#define T_timeSync 20      // timeSync service 
#define T_WiFi 21          // WiFi service
#define T_PVoutput 22      // PVoutput class 
#define T_samplePhase 23   // Sample phase (within samplePower) 
#define T_RTCWDT 24        // Dead man pedal service
#define T_CSVquery 25      // CSVquery
#define T_xurl 26          // xurl 
#define T_utility 27       // Miscelaneous utilities 
#define T_EXPORTLOG 28     // Export log
#define T_influx2 29       // influxDB_v2_uploader 
#define T_influx2Config 30 // influx2 configuration 
#define T_uploader 31      // Uploader base class
#define T_influx1 32       // influxDB_v1_uploader
#define T_integrator 33    // Integrator class  
#define T_Script 34
#define T_Scriptset 35                        

      // LED codes

#define LED_CONNECT_WIFI            "R.G.G..."              // Connecting to WiFi, AP active
#define LED_CONNECT_WIFI_NO_RTC     "R.R.G..."              // Connecting to WiFi, AP active, nofail
#define LED_SD_INIT_FAILURE         "G.R.R..."              // SD initialization failed
#define LED_DUMPING_LOG             "R.G.R..."              // Dtatlog damage, creating diagnostic file
#define LED_HALT                    "R.R.R..."              // Fatal error, CarbixEnergyMonitor halted
#define LED_NO_CONFIG               "G.R.R.R..."            // No configuration file found
#define LED_BAD_CONFIG              "G.R.R.G..."            // Could not parse config file
#define LED_UPDATING                "R.G."                  // Downloading new release

      // ADC descriptors

#define ADC_BITS 12
#define ADC_RANGE 4096      // 2^12
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

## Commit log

2024-01-18 Fork from IoTaWatt project
    [IotaWatt4.8.brd, IotaWatt4.8.sch, IotaWatt5.0.brd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]
2024-02-01 Change config file.
    [config.txt]

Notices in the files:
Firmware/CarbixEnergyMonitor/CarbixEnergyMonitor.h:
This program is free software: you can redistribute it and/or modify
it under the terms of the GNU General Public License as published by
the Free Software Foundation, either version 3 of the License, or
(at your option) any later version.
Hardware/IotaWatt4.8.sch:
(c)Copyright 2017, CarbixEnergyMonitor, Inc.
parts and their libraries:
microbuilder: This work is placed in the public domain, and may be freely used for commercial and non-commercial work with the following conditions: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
